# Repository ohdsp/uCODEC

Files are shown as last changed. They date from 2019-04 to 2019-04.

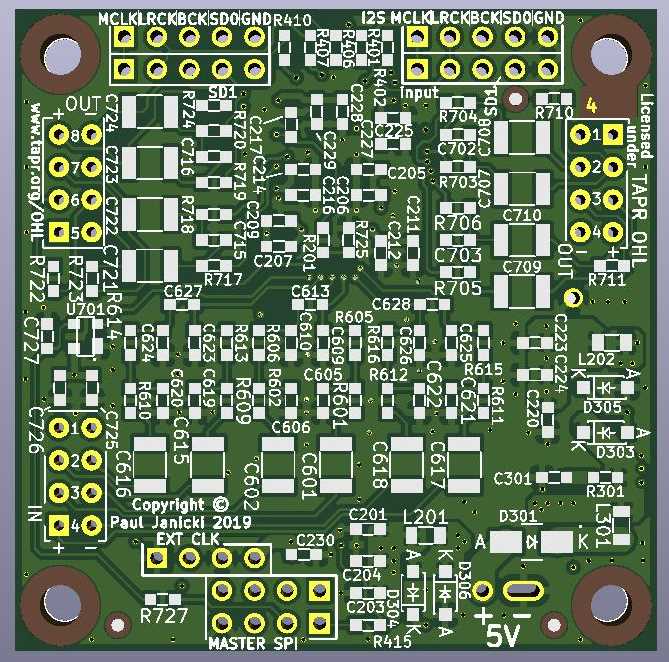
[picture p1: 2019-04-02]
JPEGs/uCODEC-1.0-Bottom-Small.jpg

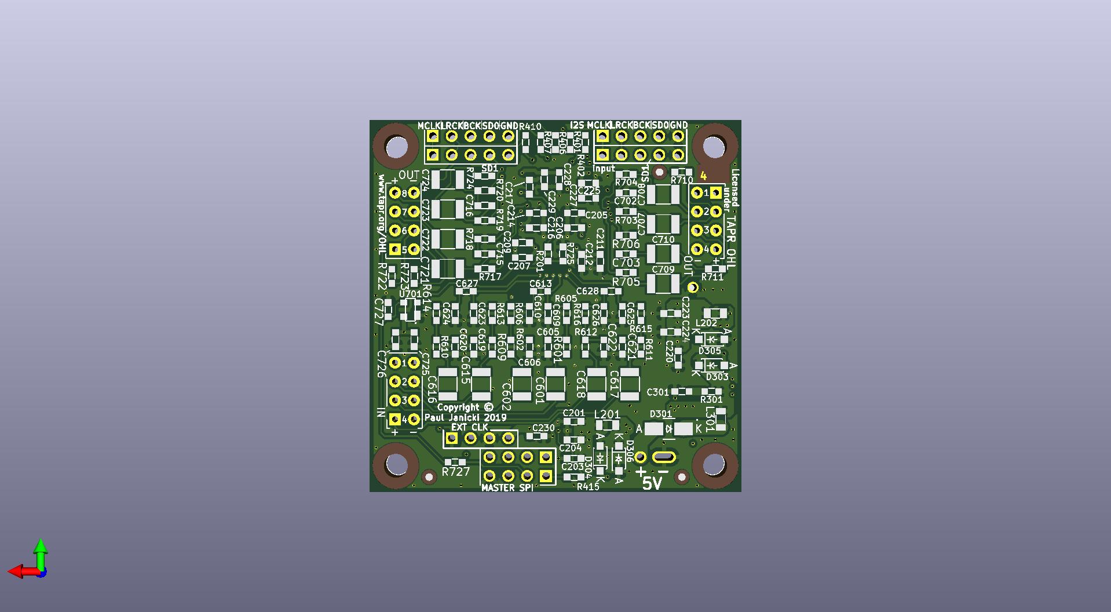
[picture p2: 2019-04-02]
JPEGs/uCODEC-1.0-Bottom.jpg

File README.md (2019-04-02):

# [Open Hardware DSP Platform](www.ohdsp.org)
## uCODEC 1.0 
### A 5cm x 5cm CODEC board using Analog Device AD1939
### 8 Differential Outputs
### 4 Differential Inputs
---
# README
### Disclaimer
Copyright Paul Janicki 2019

Licensed under the TAPR Open Hardware License (www.tapr.org/OHL)

This documentation is distributed WITHOUT ANY EXPRESS OR IMPLIED WARRANTY, INCLUDING OF MERCHANTABILITY, SATISFACTORY QUALITY AND FITNESS FOR A PARTICULAR PURPOSE.

### What is this repository for?

**Quick summary**

This is a simple 4 input, 8 output, ADC/DAC board using the Analog Devices AD1939 CODEC

This board forms part the of the open hardware DSP platform which is designed to be a highly customisable and flexible DSP platform. 

This repository contains the KiCad design files, manufacturing Gerber/drill files, and PDF/drawing files for this board.

### What is the project folder structure?
Most folder names are self explanatory. Starting from the top level:
*uCODEC*
+ *Bill of Materials*  - This contains the bill of materials in CVS, LibreOffice Calc and XML formats
+ *Drawings* - This contains PDF and SVG Schematic and PCB files
+ *Gerbers* - This contains the PCB Gerbers and drill drawings for manufacture, there is also a zip file ready to send to most manufacturers
+ *KiCad* - This contains the original KiCad schematic and PCB design files

### How do I get set up?

**Summary of set up**

1. Set your self up a directory on a local disk, something simple will make life easier (eg C:\Electronics on Windows as used here), but anywhere will do just fine.
2. Download the Kicad-Libs from [https://github.com/ohdsp/KiCad-Libs](https://github.com/ohdsp/KiCad-Libs) and place in C:\Electronics\Kicad-Libs (or your chosen folder) 
3. Create a OHDSP subdirectory in C:\Electronics (so C:\Electronics\OHDSP)
3. Download this project to C:\Electronics\OHDSP\uCODEC
4. Fire up Kicad
5. Open the main project file C:\Electronics\OHDSP\uCODEC\KiCad\uCODEC.pro
7. Do as you wish with the project, just keep it under the TAPR Open Hardware License.
Note: For library issues see below.

Make sure your git setup doesn't exclude files used in the project (like .LIB files) or things may go wrong down the line.

**KiCad Library Configuration**

Note that libraries are setup using relative paths, if you follow the above instructions things should work just fine. Below is the default library setup.

To setup eeschema component libraries:
From KiCad main window go to menu Tools -> Edit Schematic Symbols. In the new Window go to menu Preferences -> Manage Symbol Libraries.

On the new "Symbol Libraries" window select the "Project Specific Libraries" tab. The "Append Library" and "Remove Library" buttons can be used to add/remove enteries.
The standard setup is:

| | Active | Nickname | Library Path | Plugin Type | Options | Description |
|---|---|---|---|---|---|---|
| 1 | Ticked | power | ${KICAD_SYMBOL_DIR}/power.lib | Legacy | (blank) | (blank) |
| 2 | Ticked | MyKiCadLibs-Lib | ${KIPRJMOD}/../../../KiCad-Libs/MyKiCadLibs-Lib.lib | Legacy | (blank) | (blank) |

${KICAD_SYMBOL_DIR}  is set under the Enviromnet Variable Configuration. Close Symbol Libraries dialogue and go "Preferences" -> "Configure Paths..."

${KICAD_SYMBOL_DIR} is set to C:\Program Files\KiCad\share\kicad\library - this is the default for a KiCad install on the C drive

${KIPRJMOD} is automatically set to the location of the project (.pro file), in this example this would be C:\Electronics\OHDSP\uCODEC\KiCad

To setup Pcbnew libraries:
From KiCad main window go to menu Tools -> Edit PCB Footprints. In the new Window go to menu Preferences -> Manage Symbol Libraries.

On the new "Symbol Libraries" window select the "Project Specific Libraries" tab. The "Append Library" and "Remove Library" buttons can be used to add/remove enteries.
The standard setup is:

| | Active | Nickname | Library Path | Plugin Type | Options | Description |
|---|---|---|---|---|---|---|
| 1 | Ticked | MyKiCadLibs-Footprints | ${KIPRJMOD}/../../../KiCad-Libs/MyKiCadLibs-Footprints.pretty | KiCad | (blank) | (blank) |

${KIPRJMOD} is automatically set to the location of the project (.pro file), in this example this would be C:\Electronics\OHDSP\uCODEC\KiCad

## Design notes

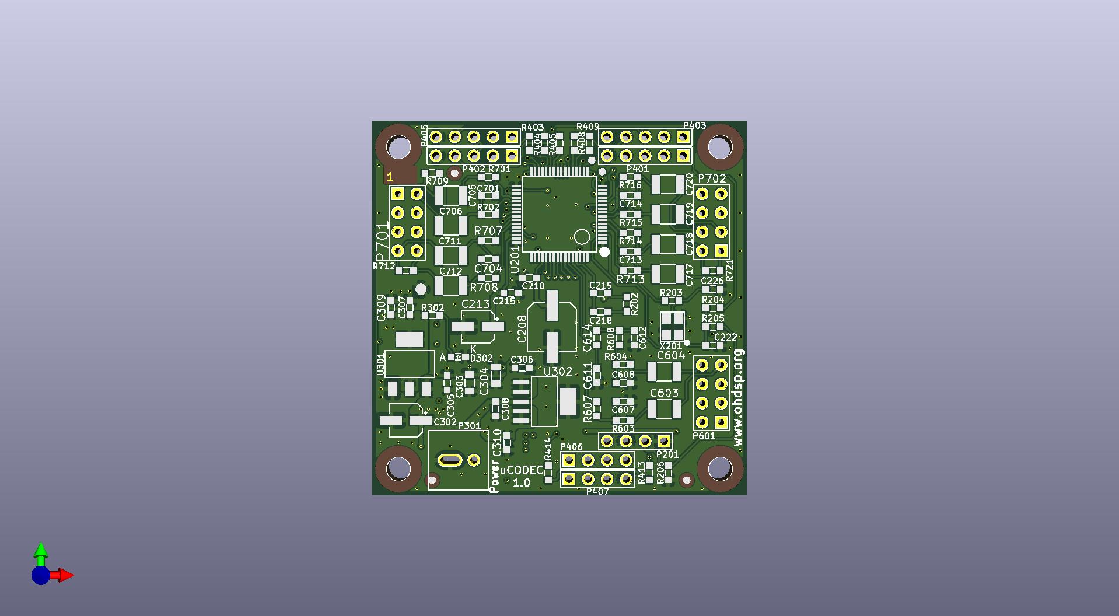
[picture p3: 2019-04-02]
JPEGs/uCODEC-1.0-Front.jpg

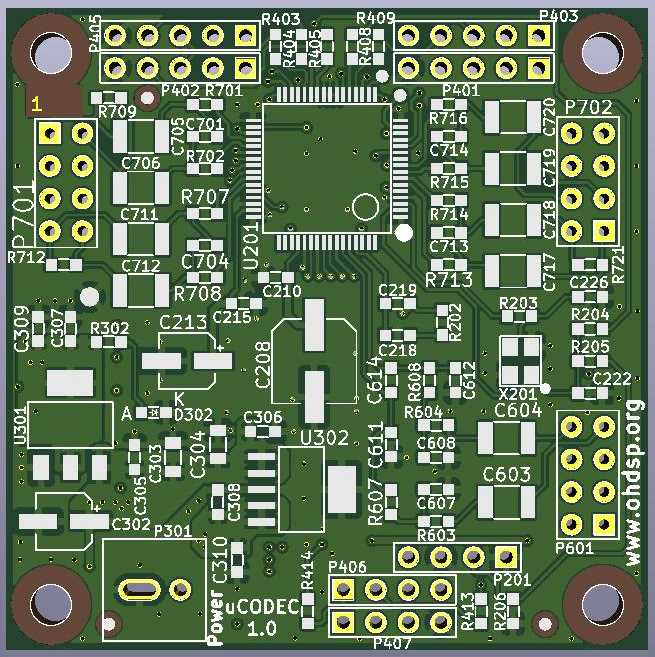
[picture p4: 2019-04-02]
JPEGs/uCODEC-1.0-Front-Small.jpg

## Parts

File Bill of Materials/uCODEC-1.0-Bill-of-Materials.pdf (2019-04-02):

ADC-PCM4202-SE-Bill-of-Materials-1.1

Page 1

### UCODEC-1.0 Bill of Materials 02 April 2019

Reference | Quantity | Footprint | Value | Description | Size | Tolerance | Type | Voltag | Power | Current
C201 C220 C301 | 3 SMD-0603 | | 100p | 'Ceramic capacitor | '0603 | '5% | 'NP0 | '50V | ' | '
C204 C205 C207 C210 C211 C214 C215 C224 C225 C228 C230 C305 C306 C307 C308 C726 | 16 SMD-0603 | | 100n | 'Ceramic capacitor | '0603 | '10% | 'X7R | '50V | ' | '
C206 C209 C212 C216 C217 C227 C229 C727 | 8 SMD-0603 | | 10n | 'Ceramic capacitor | '0603 | '10% | 'X7R | '50V | ' | '
C208 | 1 CAP-SMD-SIZE-D | | 47u | 'Low impedance aluminium electrolytic capacitor - Panasonic FP, FK or Similar | ' | ' | 'Case D SM'16V | | ' | '
C213 C302 | 2 CAP-SMD-SIZE-B | | 10u | 'Low impedance aluminium electrolytic capacitor - Panasonic FP, FK or Similar | ' | ' | 'Case B SM'16V | | ' | '
C218 | 1 SMD-0603 | | 39n | 'Ceramic capacitor | '0603 | '10% | 'X7R | '50V | ' | '
C219 | 1 SMD-0603 | | 2n2 | 'Ceramic capacitor | '0603 | '5% | 'C0G | '50V | ' | '
C222 C226 | 2 SMD-0603 | | N/F | 'Ceramic capacitor | '0603 | '5% | 'C0G | '25V | ' | '
C203 C223 C309 C310 | 4 SMD-0603 | | 22u | 'Ceramic capacitor | '0603 | '20% | 'X5R | '10V | ' | '
C303 C304 C605 C606 C607 C608 C613 C614 C619 C620 C621 C622 C627 | 2 SMD-0805 | | 22u | 'Ceramic capacitor | '0805 | '20% | 'X5R | '25V | ' | '
C628 | 12 SMD-0603 | | 100p | 'Ceramic capacitor | '0603 | '5% | 'C0G | '50V | ' | '
C609 C610 C611 C612 C623 C624 C625 C626 C701 C702 C703 C704 C713 C714 C715 C716 C601 C602 C603 C604 C615 C616 C617 C618 C705 C706 C707 | 16 SMD-0603 | | 1n | 'Ceramic capacitor | '0603 | '5% | 'C0G | '50V | ' | '
C708 C709 C710 C711 C712 C717 C718 C719 C720 C721 C722 C723 C724 | 24 SMD-1210 | | 1u | 'Acrylic capacitor | '1210 | '20% | 'Acrylic | '16V | ' | '
C725 | 1 SMD-0603 | | 10u | 'Ceramic capacitor | '0603 | '20% | 'X5R | '10V | ' | '
D301 | 1 DIODE-SMA | | B240A | 'B240A 2A 40V Schottky Rectifier - SMA (DO-214AC) | ' | ' | ' | ' | ' | '
D302 | 1 SMD-0603-LED | | LED 0603 | 'LED - SMD - Vf 1.8V to 2.2V | '0603 | ' | ' | ' | ' | '
D303 D304 D305 D306 | 4 DIODE-SOD-123 | | 1N5819HW | '1A 40V Schottky Rectifier - SOD-123 | ' | ' | ' | ' | ' | '
L201 L202 L301 | 3 SMD-0805 | | 600R@100MHz | 'Ferrite bead, current rating 1A or higher, 600R@100MHz | '0805 | ' | ' | ' | ' | '=>1A
P201 P406 P407 | 3 CONN_SIL_4_1MM | | CONN_4x1 | '2.54mm 4 way pin header or socket | ' | ' | ' | ' | ' | '
P301 | 1 CONN-2WAY-2.54mm-3.81mm-SPACING | | CONN_2x1 | '2 way screw terminal, any 2.54mm to 3.81mm pitch part | ' | ' | ' | ' | ' | '
P401 P402 P403 P405 | 4 CONN_SIL_5_1MM | | CONN_5x1 | '2.54mm 5 way pin header or socket | ' | ' | ' | ' | ' | '
P601 P701 P702 | 3 CONN_DIL_2X04 | | CONN_02X04 | '2.54mm 2x4 way pin header or socket or direct solder | ' | ' | ' | ' | ' | '
R202 | 1 SMD-0603 | | 3K32 | 'Thick or thin film resistor | '0603 | '1% | ' | ' | '63mW | '
R203 R205 R206 R406 R414 | 5 SMD-0603 | | N/F | 'Thick or thin film resistor | '0603 | '1% | ' | ' | '63mW | '
R201 R204 R404 R405 R413 R415 | 6 SMD-0603 | | 22 | 'Thick or thin film resistor | '0603 | '1% | ' | ' | '63mW | '
R301 | 1 SMD-0603 | | 47 | 'Thick or thin film resistor | '0603 | '1% | ' | ' | '63mW | '
R302 | 1 SMD-0603 | | 470 | 'Thick or thin film resistor | '0603 | '1% | ' | ' | '63mW | '
R401 R402 R403 R407 R408 R409 R410 | 7 SMD-0603 | | 0 | 'Thick or thin film resistor | '0603 | '1% | ' | ' | '63mW | '
R605 R606 R607 R608 R613 R614 R615 R616 R601 R602 R603 R604 R609 R610 R611 R612 R701 R702 R703 | 8 SMD-0603 | | 220 | 'Thick or thin film resistor | '0603 | '1% | ' | ' | '63mW | '
R704 R705 R706 R707 R708 R713 R714 R715 R716 R717 R718 R719 R720 | 24 SMD-0603 | | 1K | 'Thick or thin film resistor | '0603 | '1% | ' | ' | '63mW | '
R709 R710 R711 R712 R721 R722 R723 R724 | 8 SMD-0603 | | 220K | 'Thick or thin film resistor | '0603 | '1% | ' | ' | '63mW | '
R725 | 1 SMD-0603 | | 100K | 'Thick or thin film resistor | '0603 | '1% | ' | ' | '63mW | '
R727 | 1 SMD-0603 | | 100 | 'Thick or thin film resistor | '0603 | '1% | ' | ' | '63mW | '
U201 | 1 IC-LQFP64 | | AD1939 | 'Analog Devices AD1939WBSTZ - 4 ADC/8 DAC with PLL | ' | ' | ' | ' | ' | '
U301 | 1 IC-SOT-223 | | TLV1117LV33DCY | 'TLV1117LV 1-A, Positive Fixed-Voltage, Low-Dropout Regulator - Fixed 3V3 | ' | ' | ' | ' | ' | '
U302 | 1 IC-SOT223-6 | | TPS7A4533DCQ | 'TI TPS7A45xx Regulator | ' | ' | ' | ' | ' | '
U701 | 1 IC-SOT143 | | CAT811TTBI | 'CAT811/ADM811 - 4-Pin Microprocessor Power Supply Supervisor with Manual Reset - Active Low | ' | ' | ' | ' | ' | '
X201 | 1 XTAL_3.2x2.5_4PIN | | N/F | 'Not Fitted - 3.2x2.5mm crystal | ' | ' | ' | ' | ' | '

Licensed under the TAPR Open Hardware License (www.tapr.org/OHL)

Open Hardware DSP Platform www.ohdsp.org

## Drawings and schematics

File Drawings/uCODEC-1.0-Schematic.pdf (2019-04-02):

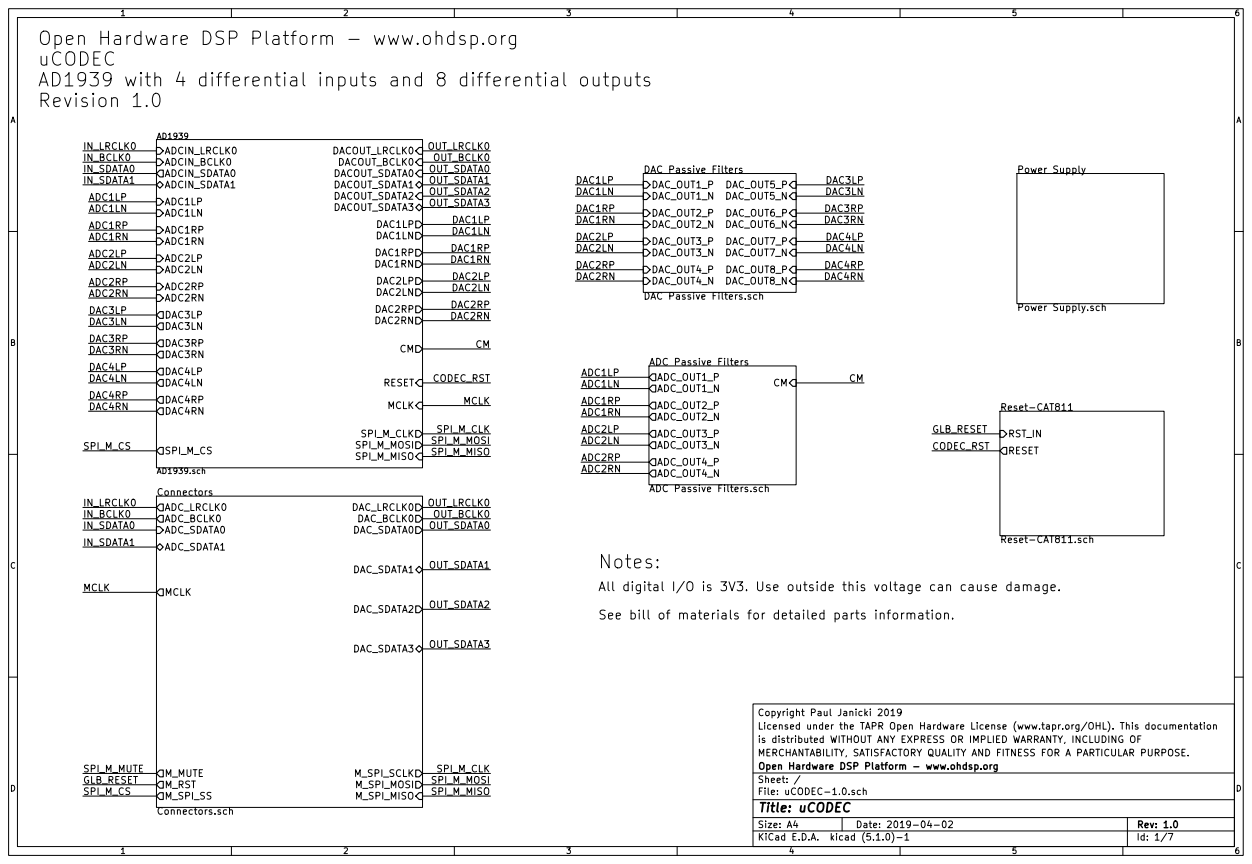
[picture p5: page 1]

Open Hardware DSP Platform - www.ohdsp.org
uCODEC
AD1939 with 4 differential inputs and 8 differential outputs
Revision 1.0

IN_BCLK0
IN_SDATA0 | OUT_SDATA0
IN_SDATA1 | OUT_SDATA1

SPI_M_MOSI
SPI_M_MISO

IN_BCLK0 | OUT_BCLK0

All digital I/O is 3V3. Use outside this voltage can cause damage.
See bill of materials for detailed parts information.

Copyright Paul Janicki 2019
Licensed under the TAPR Open Hardware License (www.tapr.org/OHL). This documentation
is distributed WITHOUT ANY EXPRESS OR IMPLIED WARRANTY, INCLUDING OF
MERCHANTABILITY, SATISFACTORY QUALITY AND FITNESS FOR A PARTICULAR PURPOSE.
File: uCODEC-1.0.sch Sheet: / Open Hardware DSP Platform - www.ohdsp.org

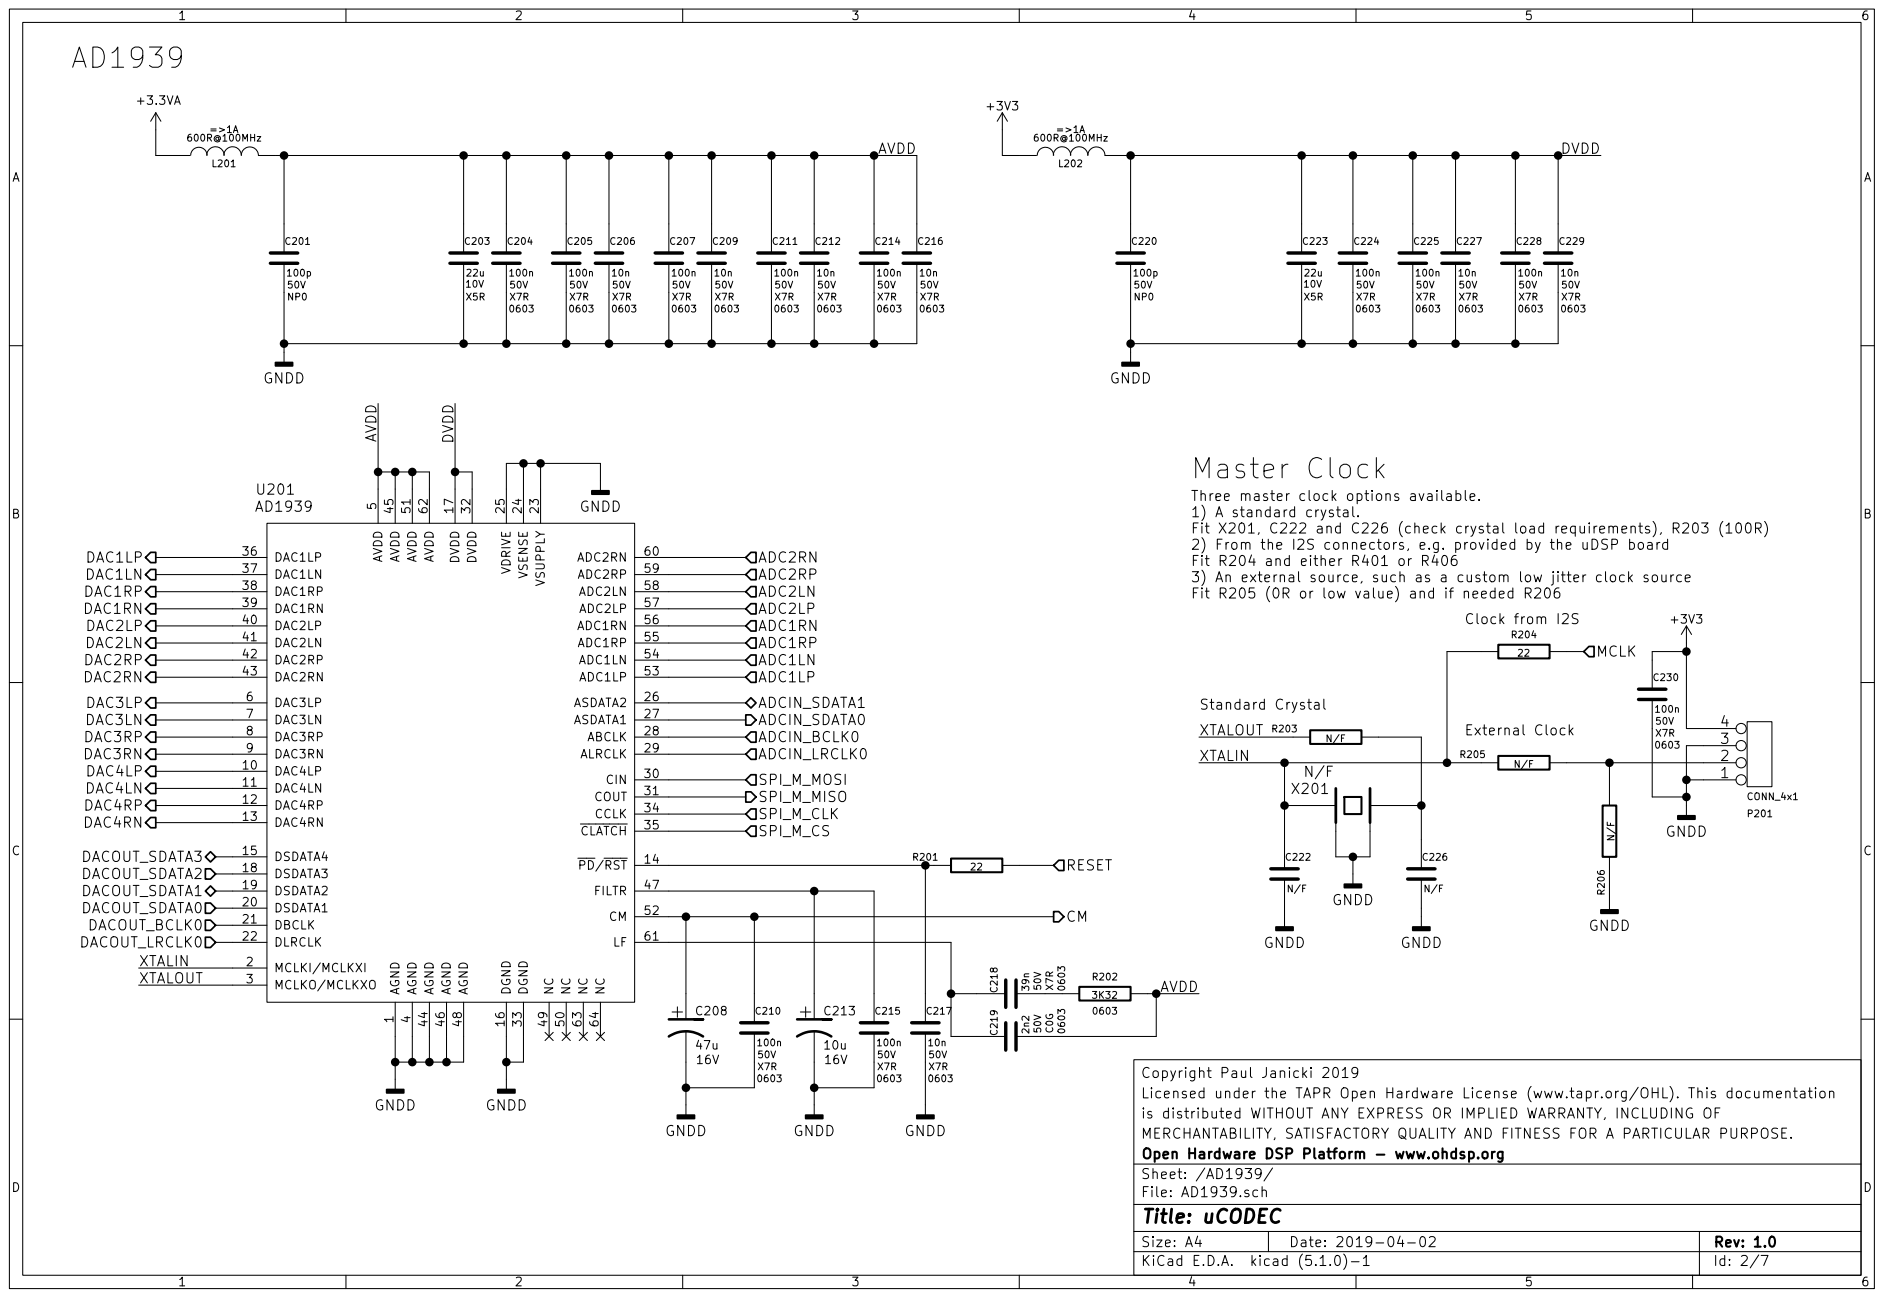
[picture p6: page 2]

4 DAC2LP 40 DAC2LN 41 DAC2RP 42 DAC2RN 43 AGND 44 AVDD 45 AGND 46 FILTR 47 AGND 48 NC 49 AVDD

Three master clock options available.
1) A standard crystal.
Fit X201, C222 and C226 (check crystal load requirements), R203 (100R)
2) From the I2S connectors, e.g. provided by the uDSP board Fit R204 and either R401 or R406

3) An external source, such as a custom low jitter clock source
Fit R205 (0R or low value) and if needed R206

Copyright Paul Janicki 2019
Licensed under the TAPR Open Hardware License (www.tapr.org/OHL). This documentation
is distributed WITHOUT ANY EXPRESS OR IMPLIED WARRANTY, INCLUDING OF
MERCHANTABILITY, SATISFACTORY QUALITY AND FITNESS FOR A PARTICULAR PURPOSE.
File: AD1939.sch Sheet: /AD1939/ Open Hardware DSP Platform - www.ohdsp.org

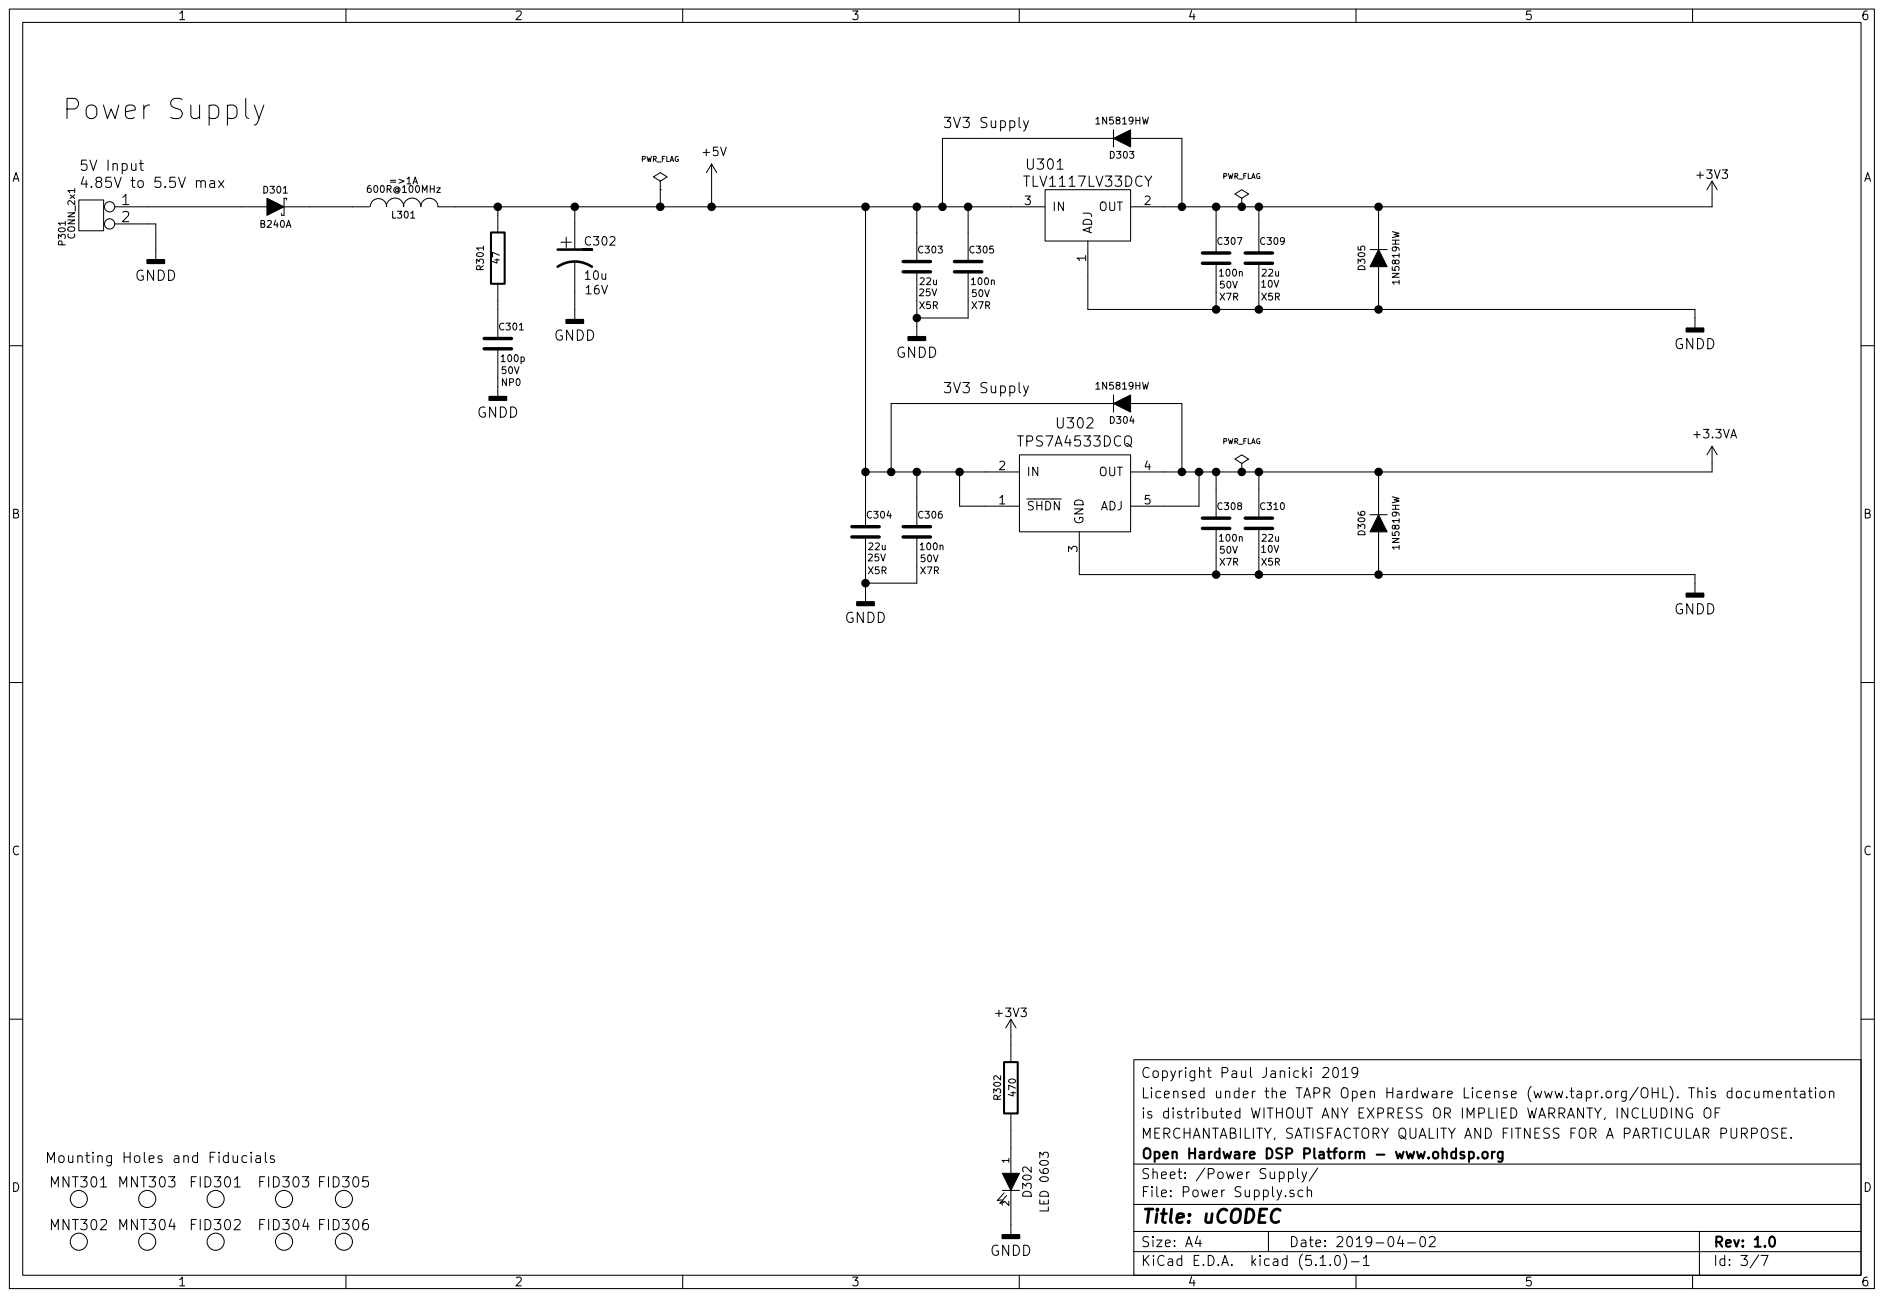
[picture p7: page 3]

Copyright Paul Janicki 2019
Licensed under the TAPR Open Hardware License (www.tapr.org/OHL). This documentation
is distributed WITHOUT ANY EXPRESS OR IMPLIED WARRANTY, INCLUDING OF
MERCHANTABILITY, SATISFACTORY QUALITY AND FITNESS FOR A PARTICULAR PURPOSE.
Open Hardware DSP Platform - www.ohdsp.org
Sheet: /Power Supply/
File: Power Supply.sch
Id: 3/7 Title: uCODEC

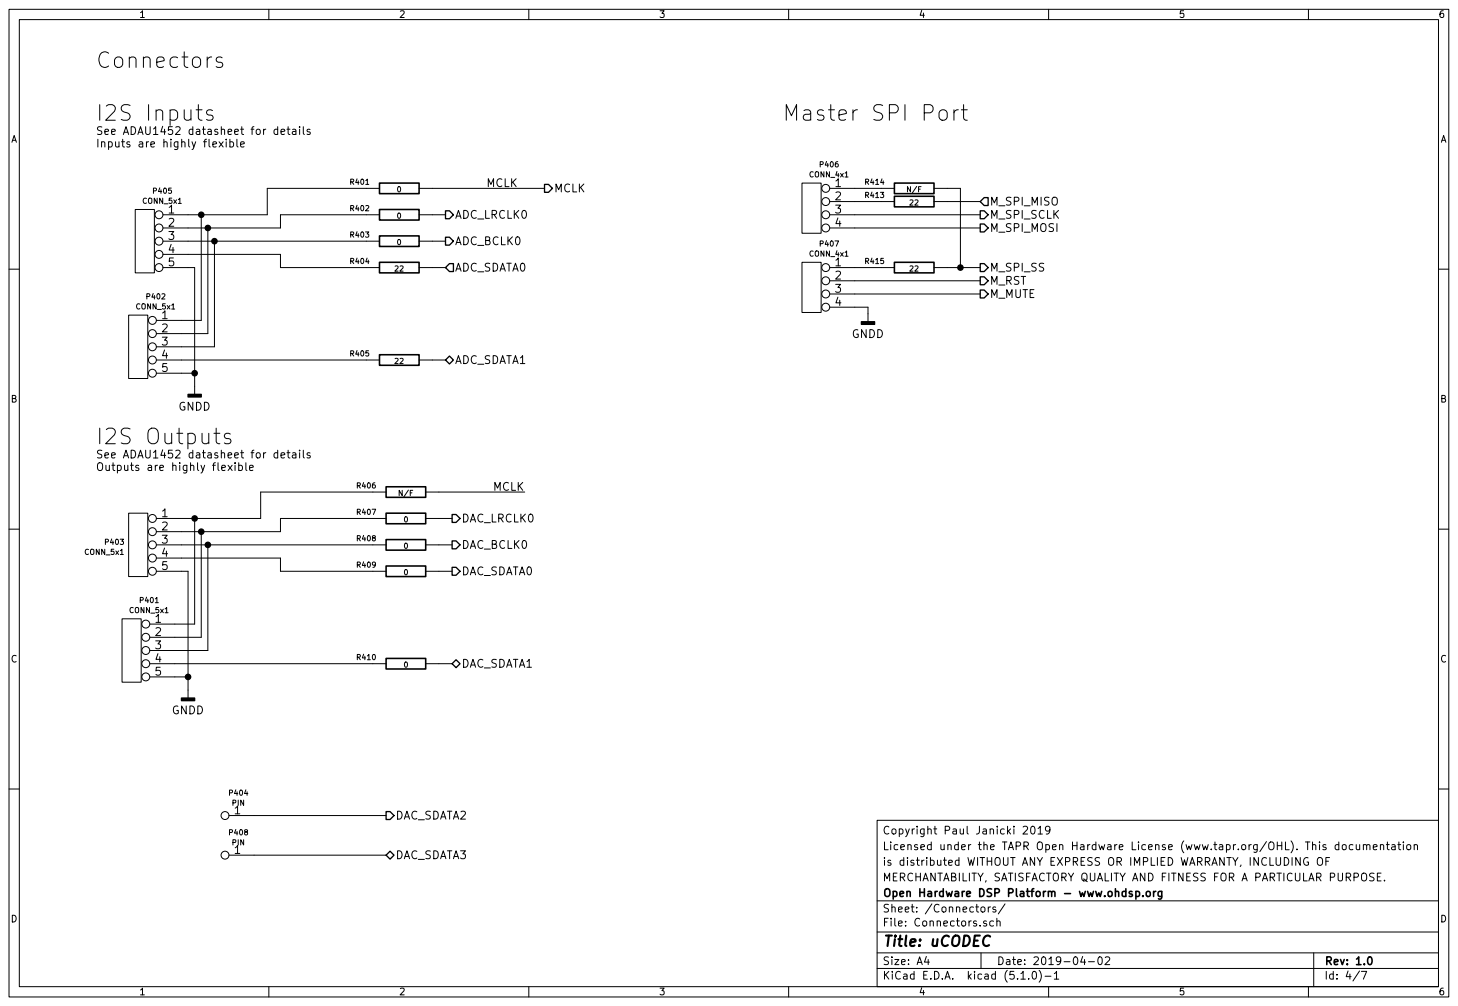
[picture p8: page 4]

I2S Inputs
See ADAU1452 datasheet for details
Inputs are highly flexible

I2S Outputs
See ADAU1452 datasheet for details Outputs are highly flexible

Copyright Paul Janicki 2019
Licensed under the TAPR Open Hardware License (www.tapr.org/OHL). This documentation
is distributed WITHOUT ANY EXPRESS OR IMPLIED WARRANTY, INCLUDING OF
MERCHANTABILITY, SATISFACTORY QUALITY AND FITNESS FOR A PARTICULAR PURPOSE.
File: Connectors.sch Sheet: /Connectors/ Open Hardware DSP Platform - www.ohdsp.org

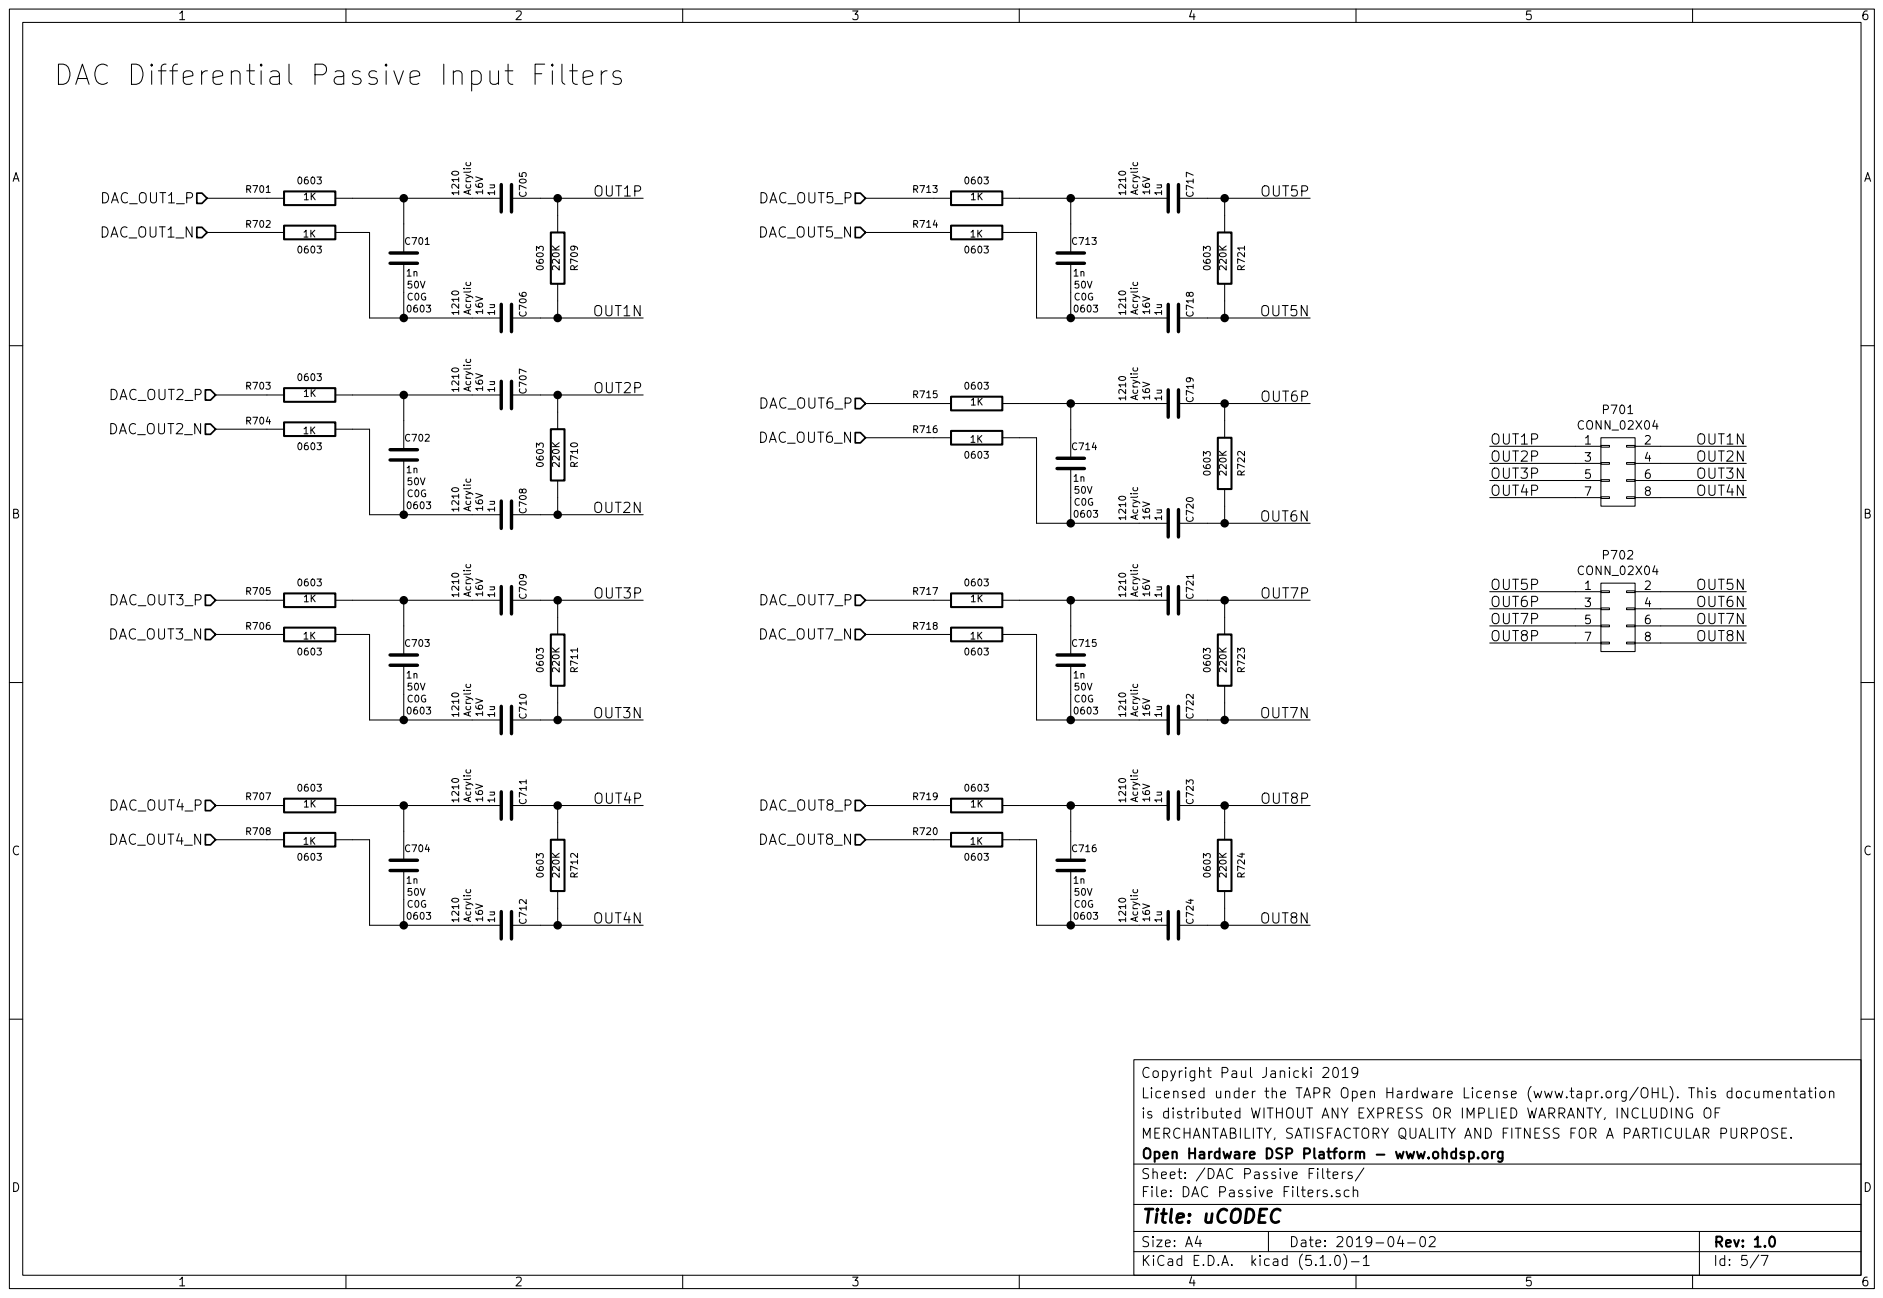
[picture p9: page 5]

DAC Differential Passive Input Filters

Licensed under the TAPR Open Hardware License (www.tapr.org/OHL). This documentation
is distributed WITHOUT ANY EXPRESS OR IMPLIED WARRANTY, INCLUDING OF
MERCHANTABILITY, SATISFACTORY QUALITY AND FITNESS FOR A PARTICULAR PURPOSE.
File: DAC Passive Filters.sch Sheet: /DAC Passive Filters/ Open Hardware DSP Platform - www.ohdsp.org

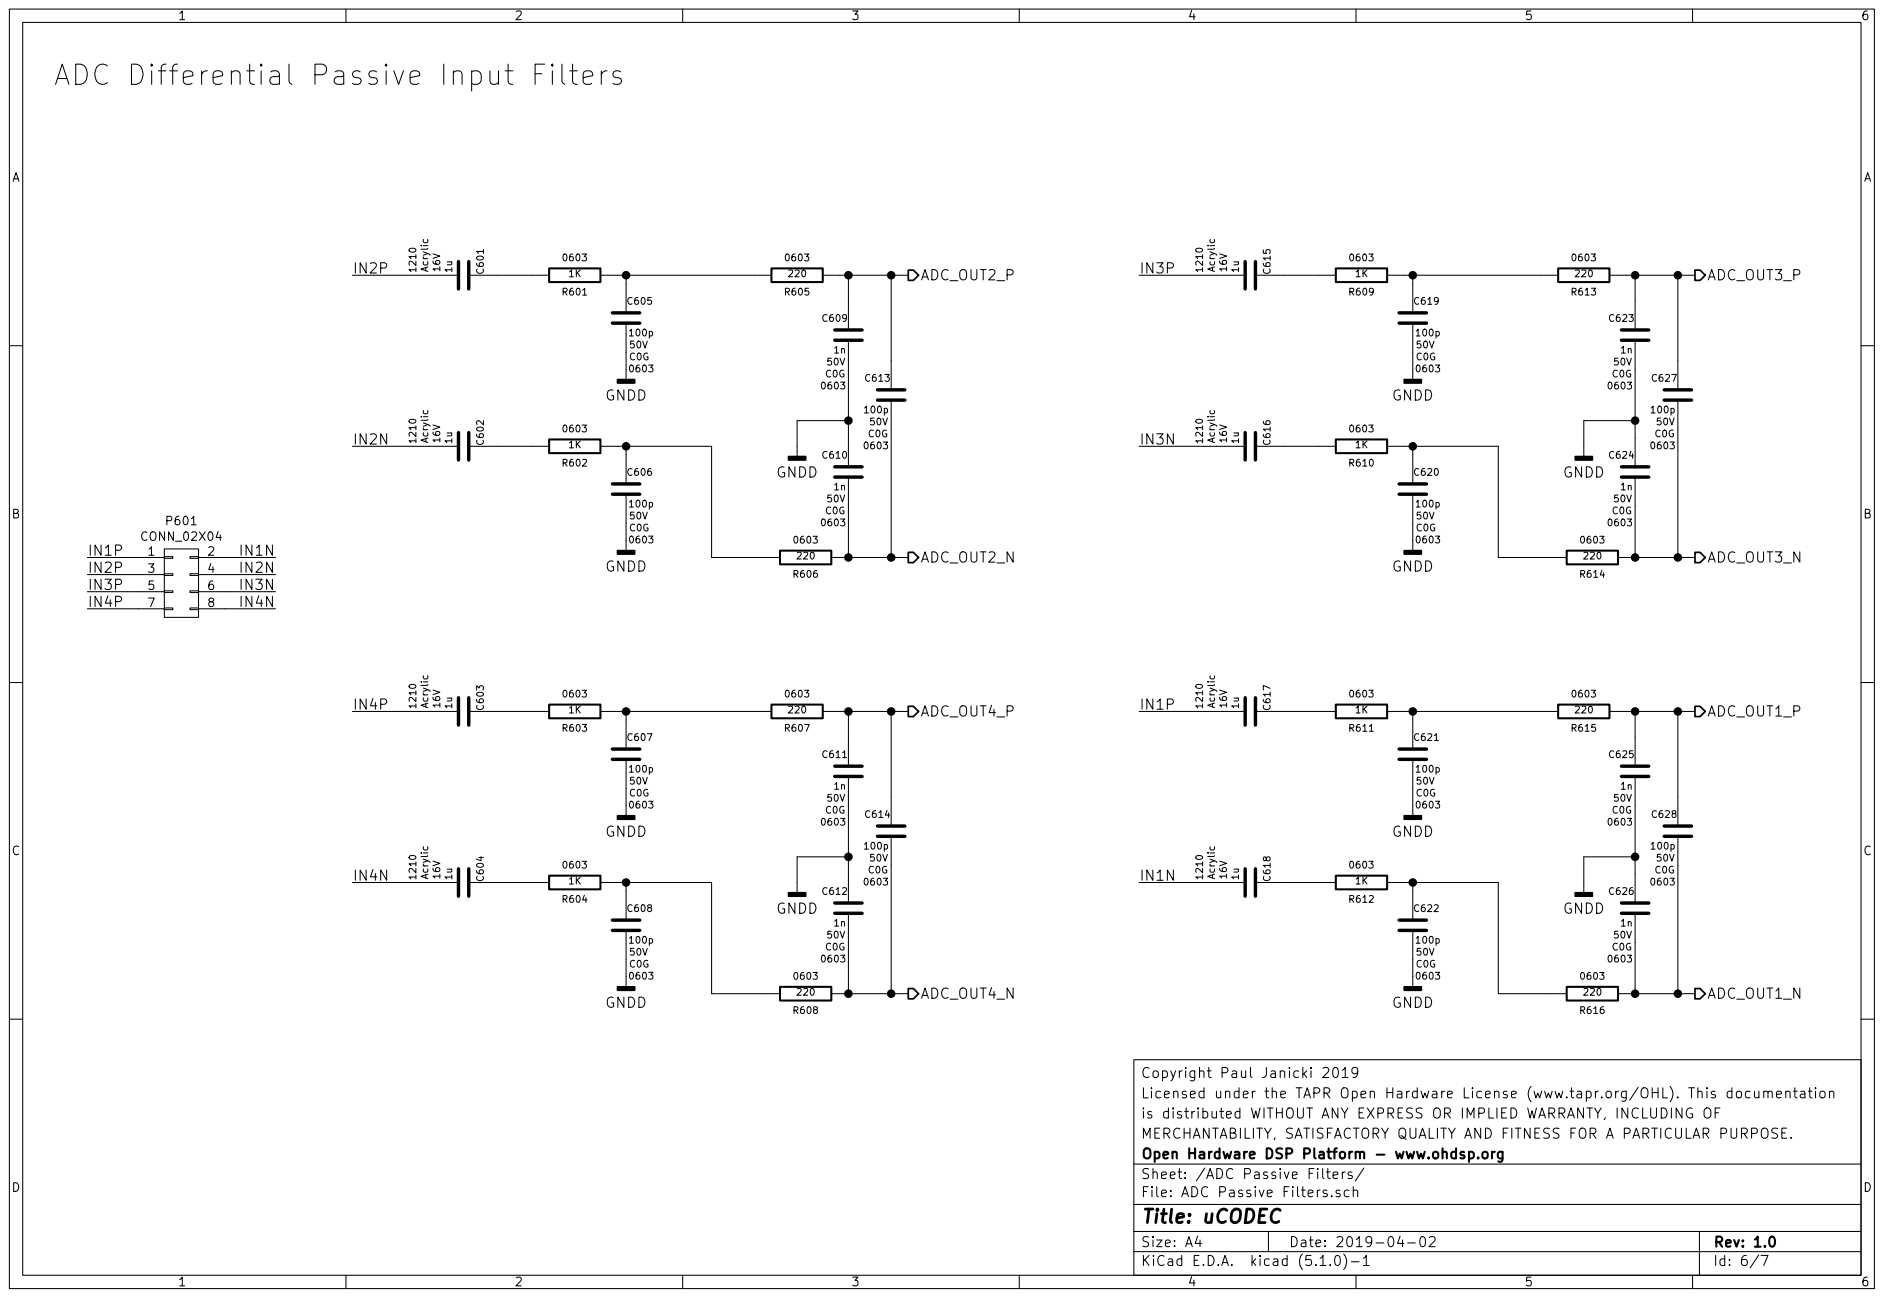
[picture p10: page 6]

ADC Differential Passive Input Filters

Copyright Paul Janicki 2019
Licensed under the TAPR Open Hardware License (www.tapr.org/OHL). This documentation
is distributed WITHOUT ANY EXPRESS OR IMPLIED WARRANTY, INCLUDING OF
MERCHANTABILITY, SATISFACTORY QUALITY AND FITNESS FOR A PARTICULAR PURPOSE.
File: ADC Passive Filters.sch Sheet: /ADC Passive Filters/ Open Hardware DSP Platform - www.ohdsp.org

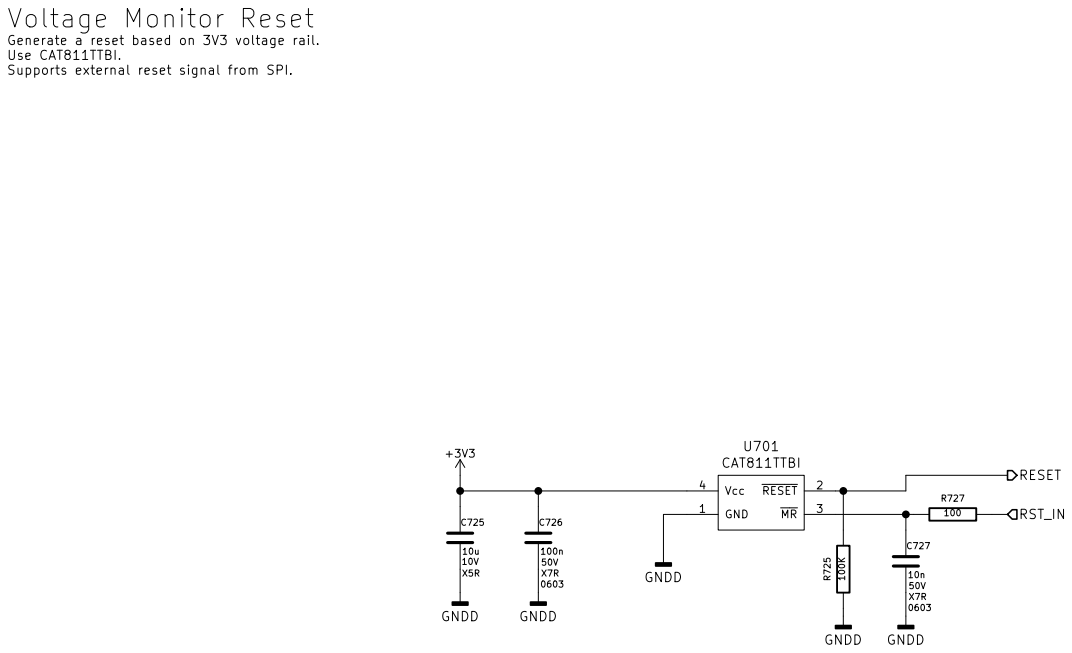
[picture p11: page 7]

Generate a reset based on 3V3 voltage rail. Use CAT811TTBI. Supports external reset signal from SPI.

Copyright Paul Janicki 2019
Licensed under the TAPR Open Hardware License (www.tapr.org/OHL). This documentation
is distributed WITHOUT ANY EXPRESS OR IMPLIED WARRANTY, INCLUDING OF
MERCHANTABILITY, SATISFACTORY QUALITY AND FITNESS FOR A PARTICULAR PURPOSE.
File: Reset-CAT811.sch Sheet: /Reset-CAT811/ Open Hardware DSP Platform - www.ohdsp.org

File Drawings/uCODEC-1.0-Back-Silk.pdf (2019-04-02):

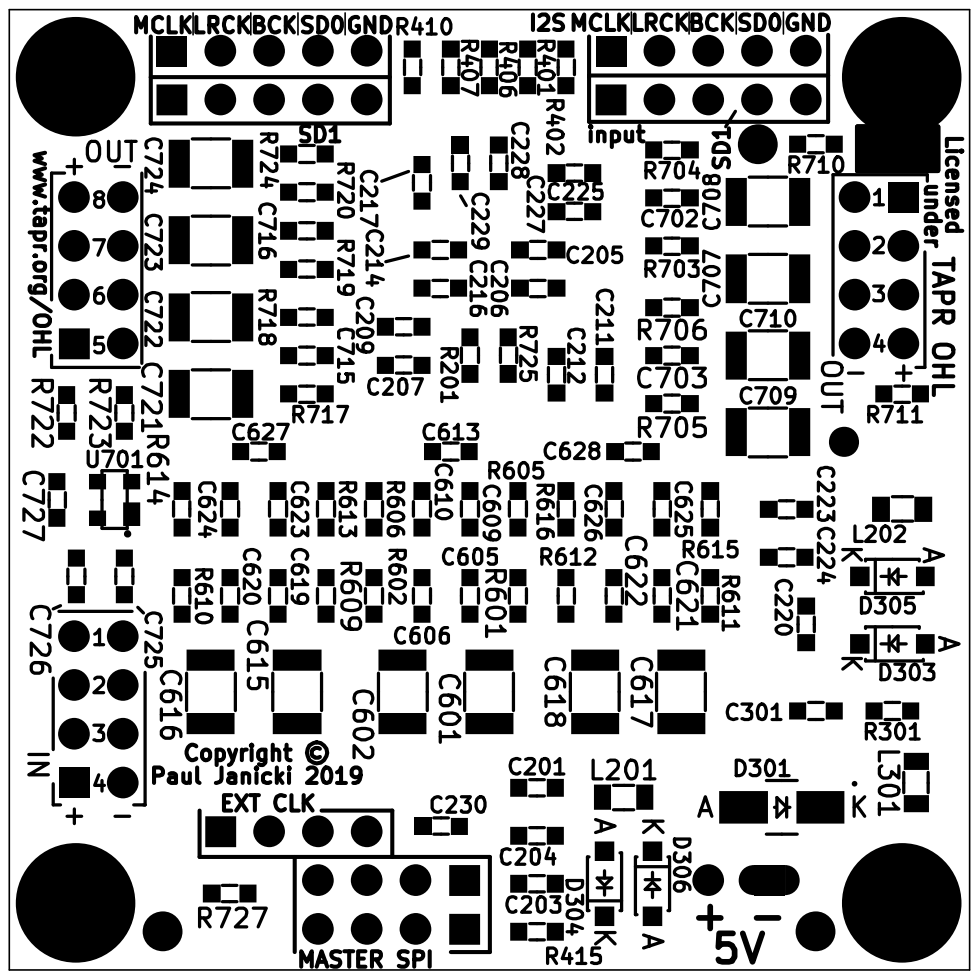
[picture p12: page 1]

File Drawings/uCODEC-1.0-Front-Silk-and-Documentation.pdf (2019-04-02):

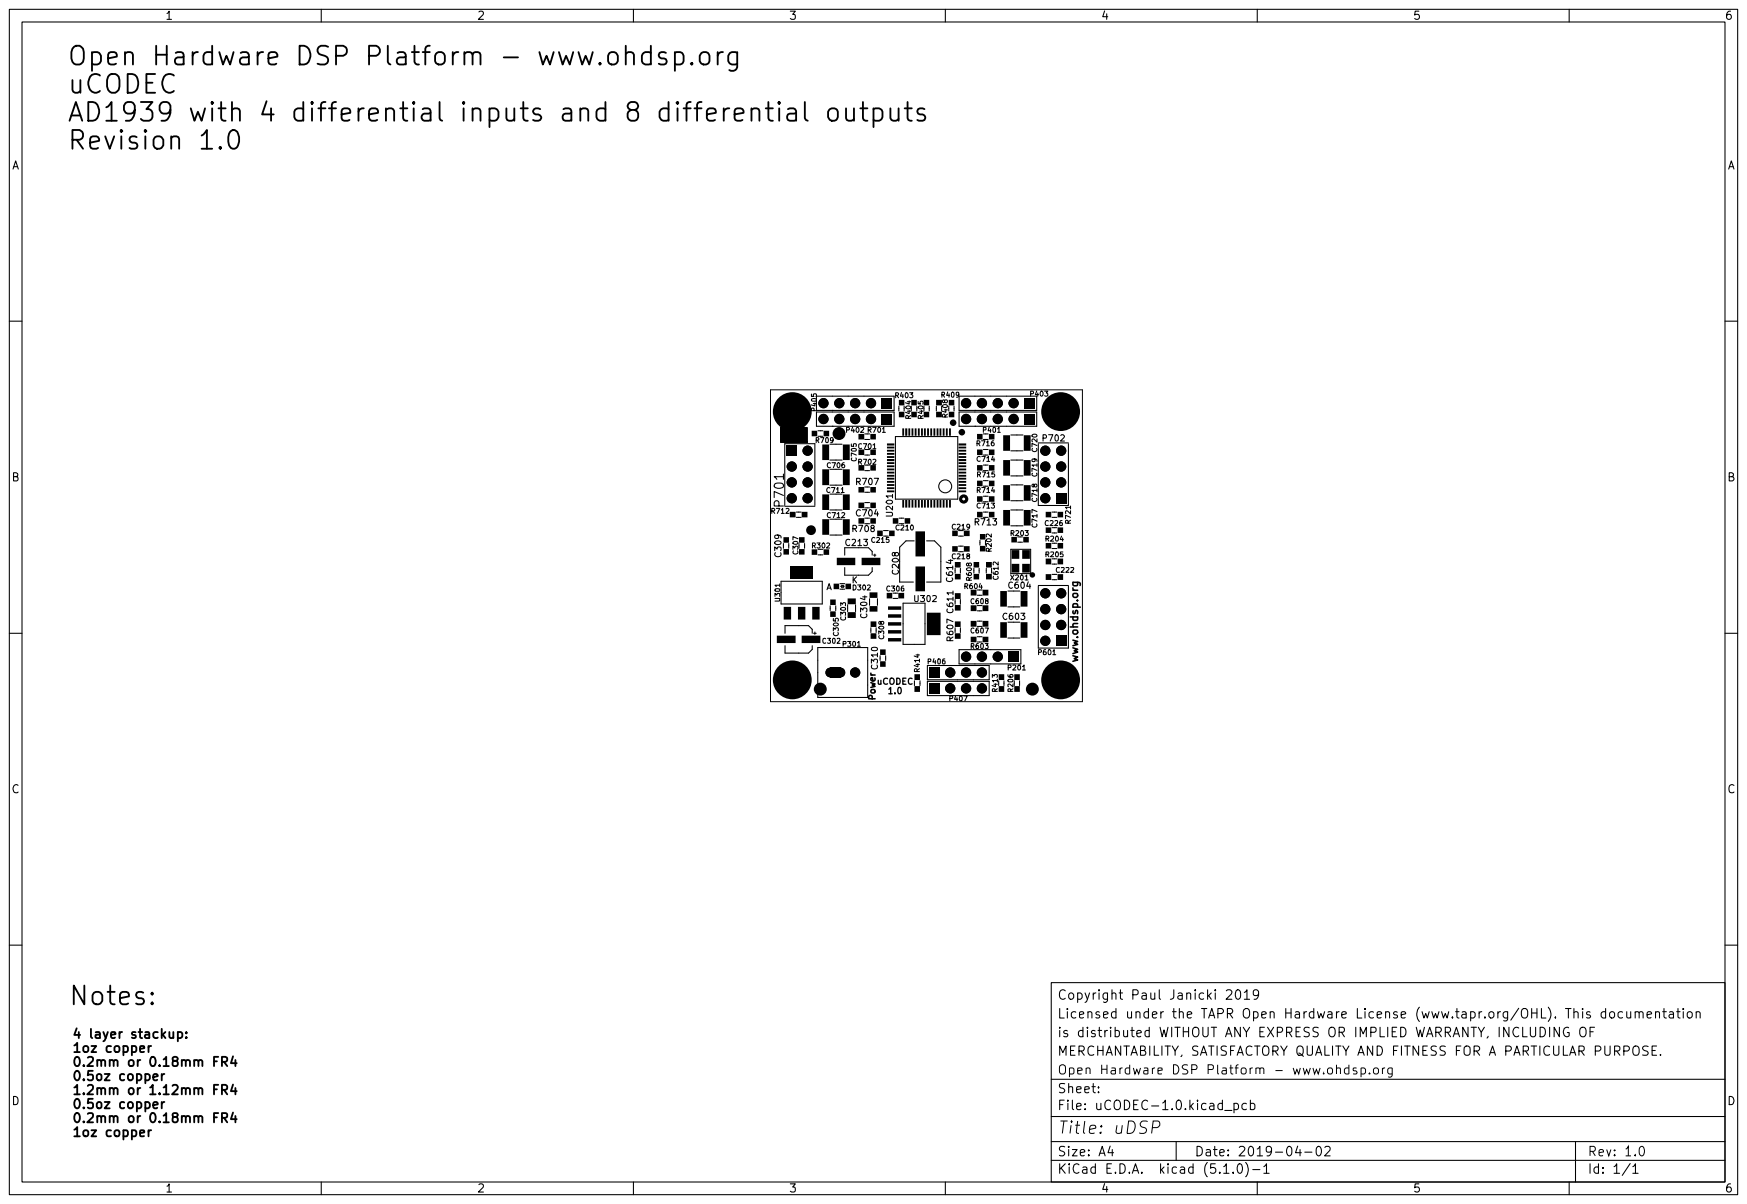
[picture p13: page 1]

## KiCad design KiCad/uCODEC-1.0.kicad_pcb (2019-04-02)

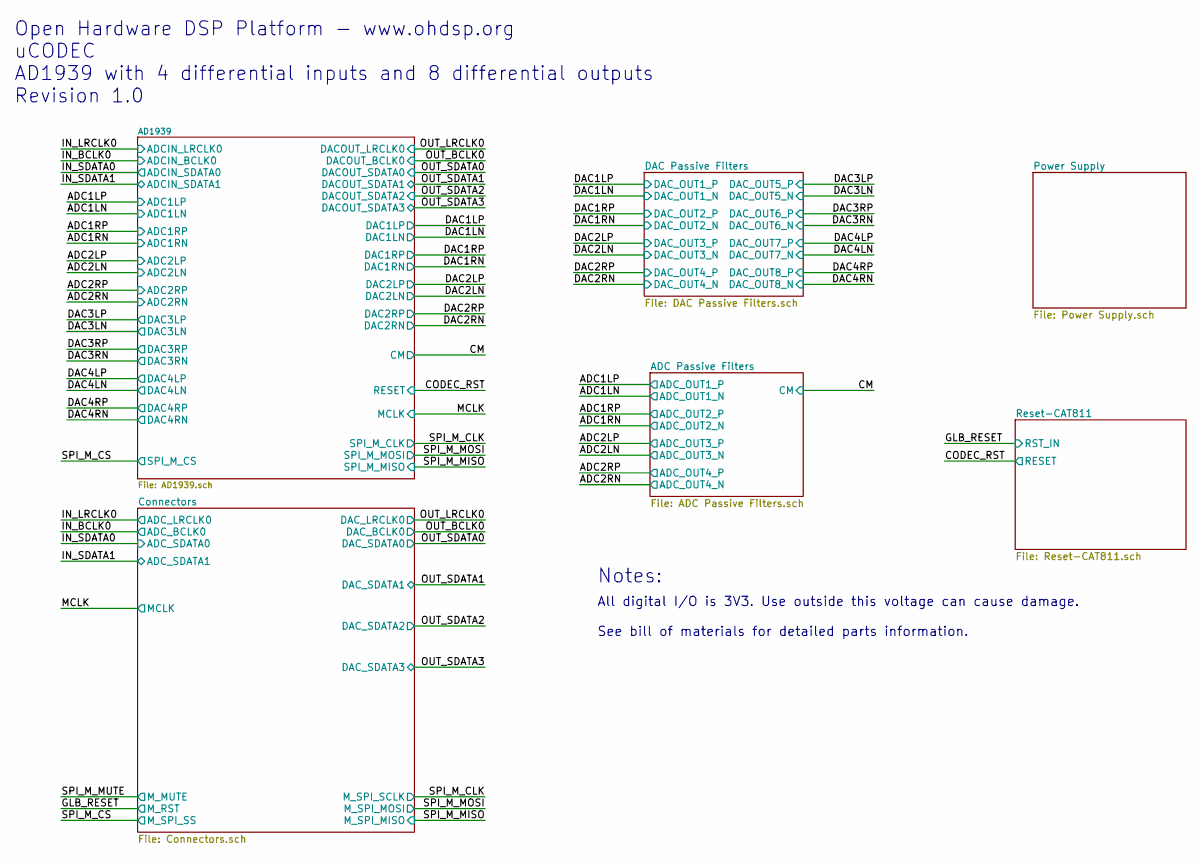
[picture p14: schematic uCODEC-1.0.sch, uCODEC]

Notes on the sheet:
All digital I/O is 3V3. Use outside this voltage can cause damage. See bill of materials for detailed parts information.
Notes:
Open Hardware DSP Platform - www.ohdsp.org uCODEC AD1939 with 4 differential inputs and 8 differential outputs Revision 1.0

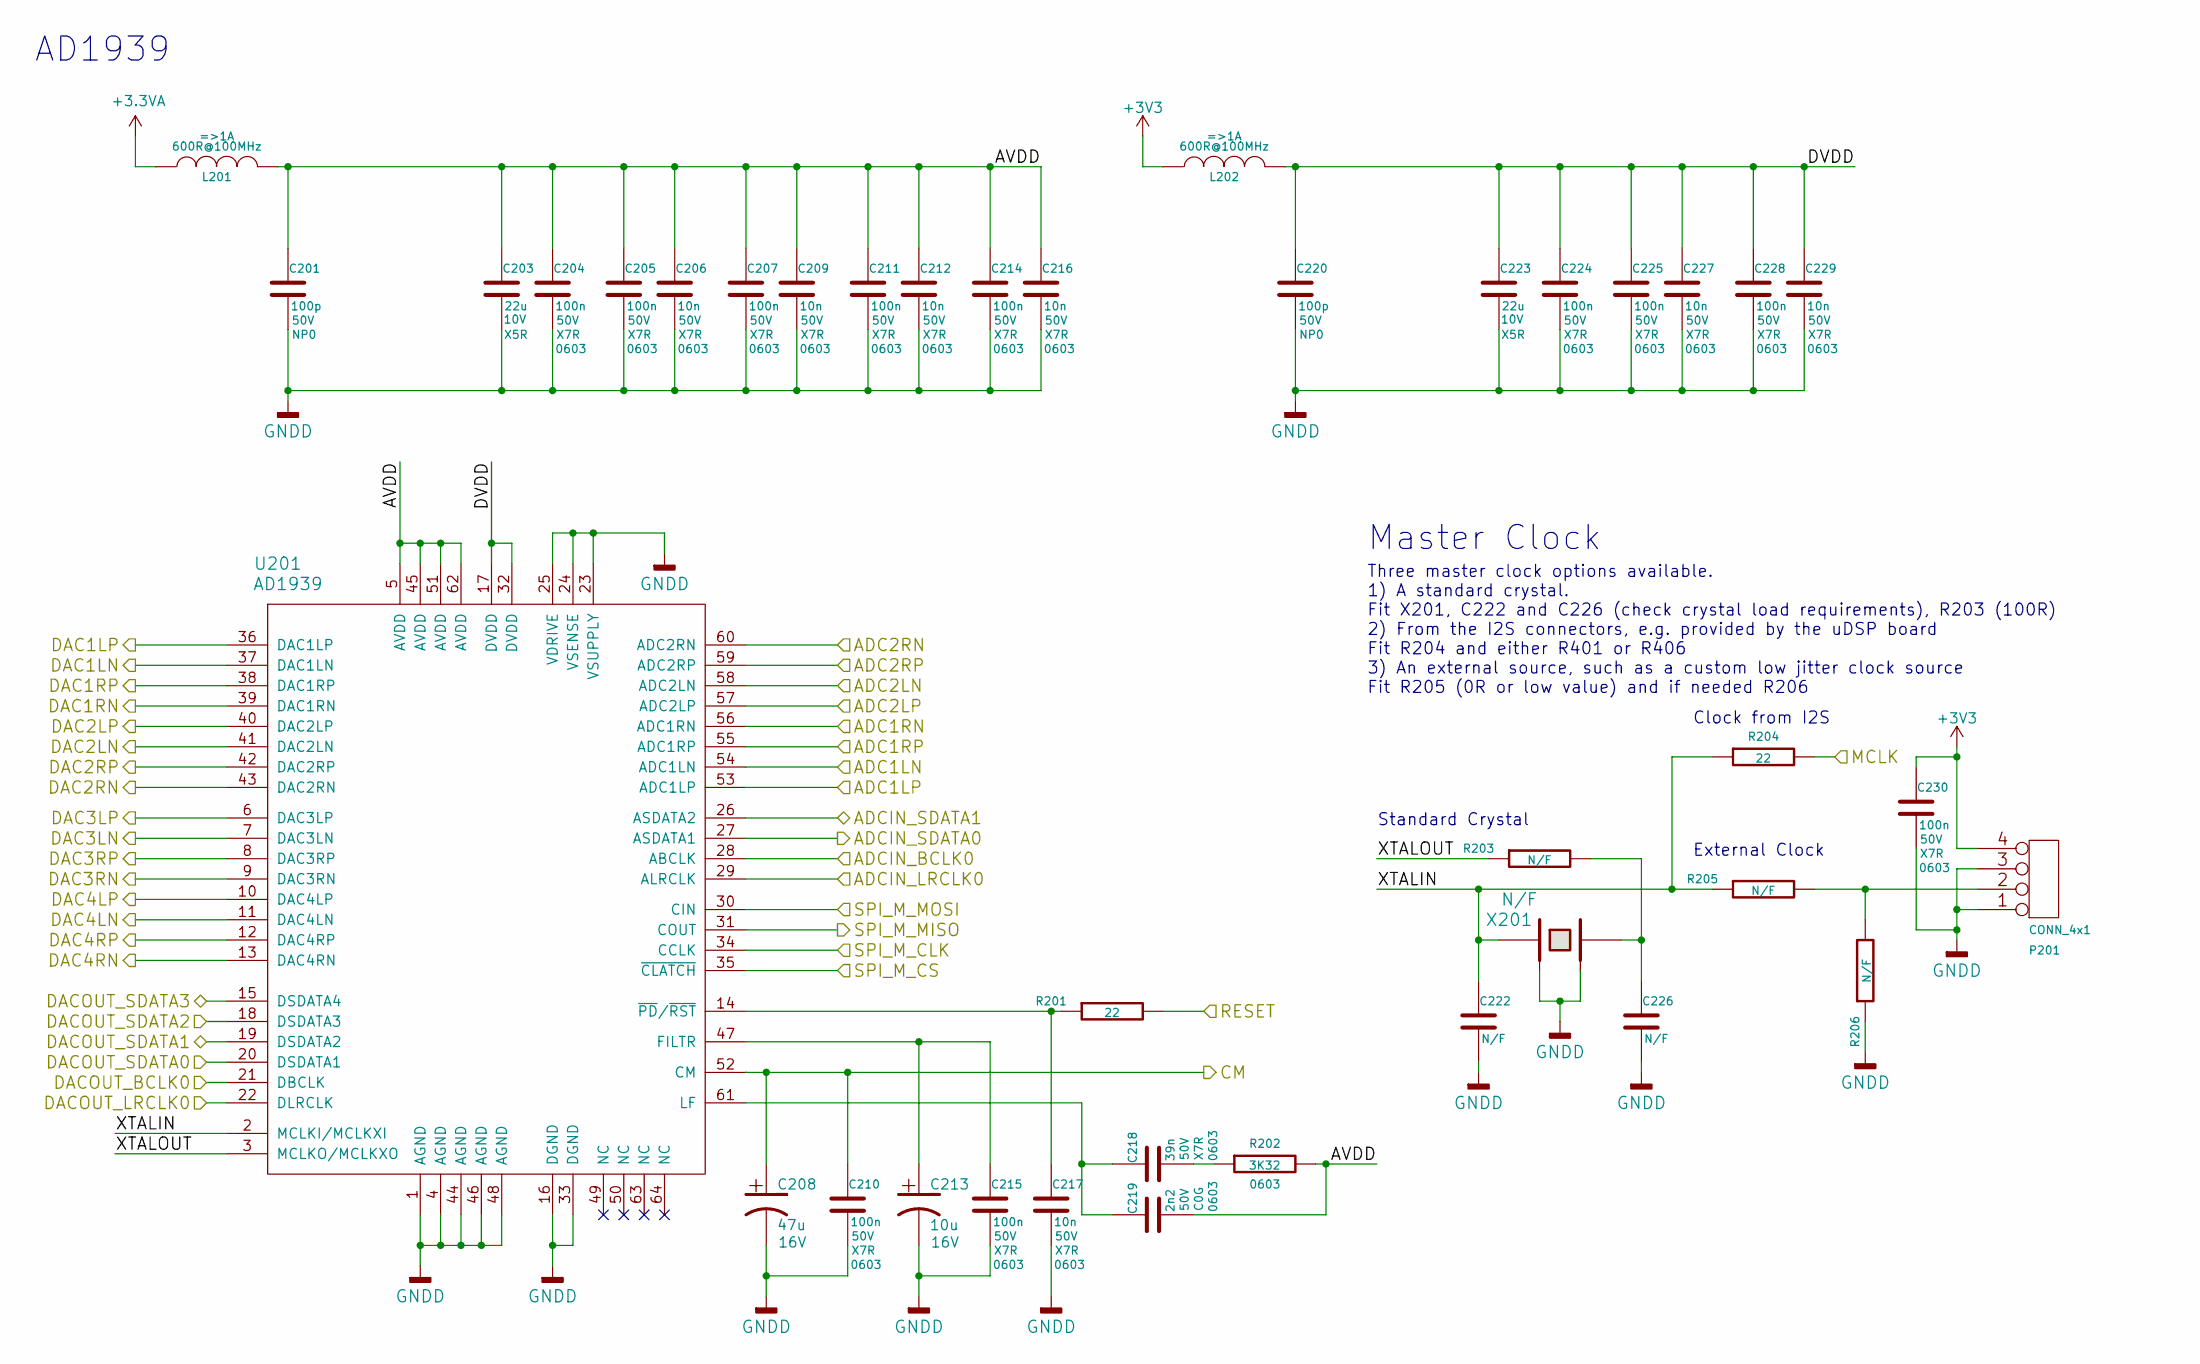
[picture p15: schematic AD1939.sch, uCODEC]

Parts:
C201, C220: 100p; SMD-0603; Voltage 50V; Tolerance 5%
C203, C223: 22u; SMD-0603; Voltage 10V; Tolerance 20%
C204, C205, C207, C210, C211, C214, C215, C224, C225, C228, C230: 100n; SMD-0603; Voltage 50V; Tolerance 10%
C206, C209, C212, C216, C217, C227, C229: 10n; SMD-0603; Voltage 50V; Tolerance 10%
C208: 47u; CAP-SMD-SIZE-D; Voltage 16V
C213: 10u; CAP-SMD-SIZE-B; Voltage 16V
C218: 39n; SMD-0603; Voltage 50V; Tolerance 10%
C219: 2n2; SMD-0603; Voltage 50V; Tolerance 5%
C222, C226: N/F; SMD-0603; Voltage 25V; Tolerance 5%
L201, L202: 600R@100MHz; SMD-0805
P201: CONN_4x1; CONN_SIL_4_1MM
R201, R204: 22; SMD-0603; Tolerance 1%
R202: 3K32; SMD-0603; Tolerance 1%
R203, R205, R206: N/F; SMD-0603; Tolerance 1%
U201: AD1939; IC-LQFP64
X201: N/F; XTAL_3.2x2.5_4PIN

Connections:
+3.3VA: L201.1; also elsewhere on the board
+3V3: C230.1, L202.1, P201.4; also elsewhere on the board
/AD1939/AVDD: C201.1, C203.1, C204.1, C205.1, C206.1, C207.1, C209.1, C211.1, C212.1, C214.1, C216.1, C219.2, L201.2, R202.2, U201.5 (AVDD), U201.45 (AVDD), U201.51 (AVDD), U201.62 (AVDD)
/AD1939/DVDD: C220.1, C223.1, C224.1, C225.1, C227.1, C228.1, C229.1, L202.2, U201.17 (DVDD), U201.32 (DVDD)
/AD1939/XTALIN: C222.1, R204.1, R205.1, U201.2 (MCLKI/MCLKXI), X201.1
/AD1939/XTALOUT: R203.1, U201.3 (MCLKO/MCLKXO)
/ADC1RN: U201.56 (ADC1RN); also elsewhere on the board
/ADC2LN: U201.58 (ADC2LN); also elsewhere on the board
/ADC2LP: U201.57 (ADC2LP); also elsewhere on the board
/ADC2RN: U201.60 (ADC2RN); also elsewhere on the board
/ADC2RP: U201.59 (ADC2RP); also elsewhere on the board
/CM: C208.1, C210.1, U201.52 (CM)
/CODEC_RST: R201.2; also elsewhere on the board
/DAC1LN: U201.37 (DAC1LN); also elsewhere on the board
/DAC1LP: U201.36 (DAC1LP); also elsewhere on the board
/DAC1RN: U201.39 (DAC1RN); also elsewhere on the board
/DAC1RP: U201.38 (DAC1RP); also elsewhere on the board
/DAC2LN: U201.41 (DAC2LN); also elsewhere on the board
/DAC2LP: U201.40 (DAC2LP); also elsewhere on the board
/DAC2RN: U201.43 (DAC2RN); also elsewhere on the board
/DAC2RP: U201.42 (DAC2RP); also elsewhere on the board
/DAC3LN: U201.7 (DAC3LN); also elsewhere on the board
/DAC3LP: U201.6 (DAC3LP); also elsewhere on the board
/DAC3RN: U201.9 (DAC3RN); also elsewhere on the board
/DAC3RP: U201.8 (DAC3RP); also elsewhere on the board
/DAC4LN: U201.11 (DAC4LN); also elsewhere on the board
/DAC4LP: U201.10 (DAC4LP); also elsewhere on the board
/DAC4RN: U201.13 (DAC4RN); also elsewhere on the board
/DAC4RP: U201.12 (DAC4RP); also elsewhere on the board
/IN_BCLK0: U201.28 (ABCLK); also elsewhere on the board
/IN_LRCLK0: U201.29 (ALRCLK); also elsewhere on the board
/IN_SDATA0: U201.27 (ASDATA1); also elsewhere on the board
/IN_SDATA1: U201.26 (ASDATA2); also elsewhere on the board
/MCLK: R204.2; also elsewhere on the board
/OUT_BCLK0: U201.21 (DBCLK); also elsewhere on the board
/OUT_LRCLK0: U201.22 (DLRCLK); also elsewhere on the board
/OUT_SDATA0: U201.20 (DSDATA1); also elsewhere on the board
/OUT_SDATA1: U201.19 (DSDATA2); also elsewhere on the board
/OUT_SDATA2: U201.18 (DSDATA3); also elsewhere on the board
/OUT_SDATA3: U201.15 (DSDATA4); also elsewhere on the board
/SPI_M_CLK: U201.34 (CCLK); also elsewhere on the board
/SPI_M_CS: U201.35 (~CLATCH); also elsewhere on the board
/SPI_M_MISO: U201.31 (COUT); also elsewhere on the board
/SPI_M_MOSI: U201.30 (CIN); also elsewhere on the board
unnamed: C213.1, C215.1, U201.47 (FILTR)
unnamed: C217.1, R201.1, U201.14 (~PD~/~RST)
unnamed: C218.1, C219.1, U201.61 (LF)
unnamed: C218.2, R202.1
unnamed: C226.1, R203.2, X201.3
unnamed: P201.2, R205.2, R206.2

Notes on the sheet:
Master Clock
Standard Crystal
External Clock
AD1939
Clock from I2S
Three master clock options available. 1) A standard crystal. Fit X201, C222 and C226 (check crystal load requirements), R203 (100R) 2) From the I2S connectors, e.g. provided by the uDSP board Fit R204 and either R401 or R406 3) An external source, such as a custom low jitter clock source Fit R205 (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

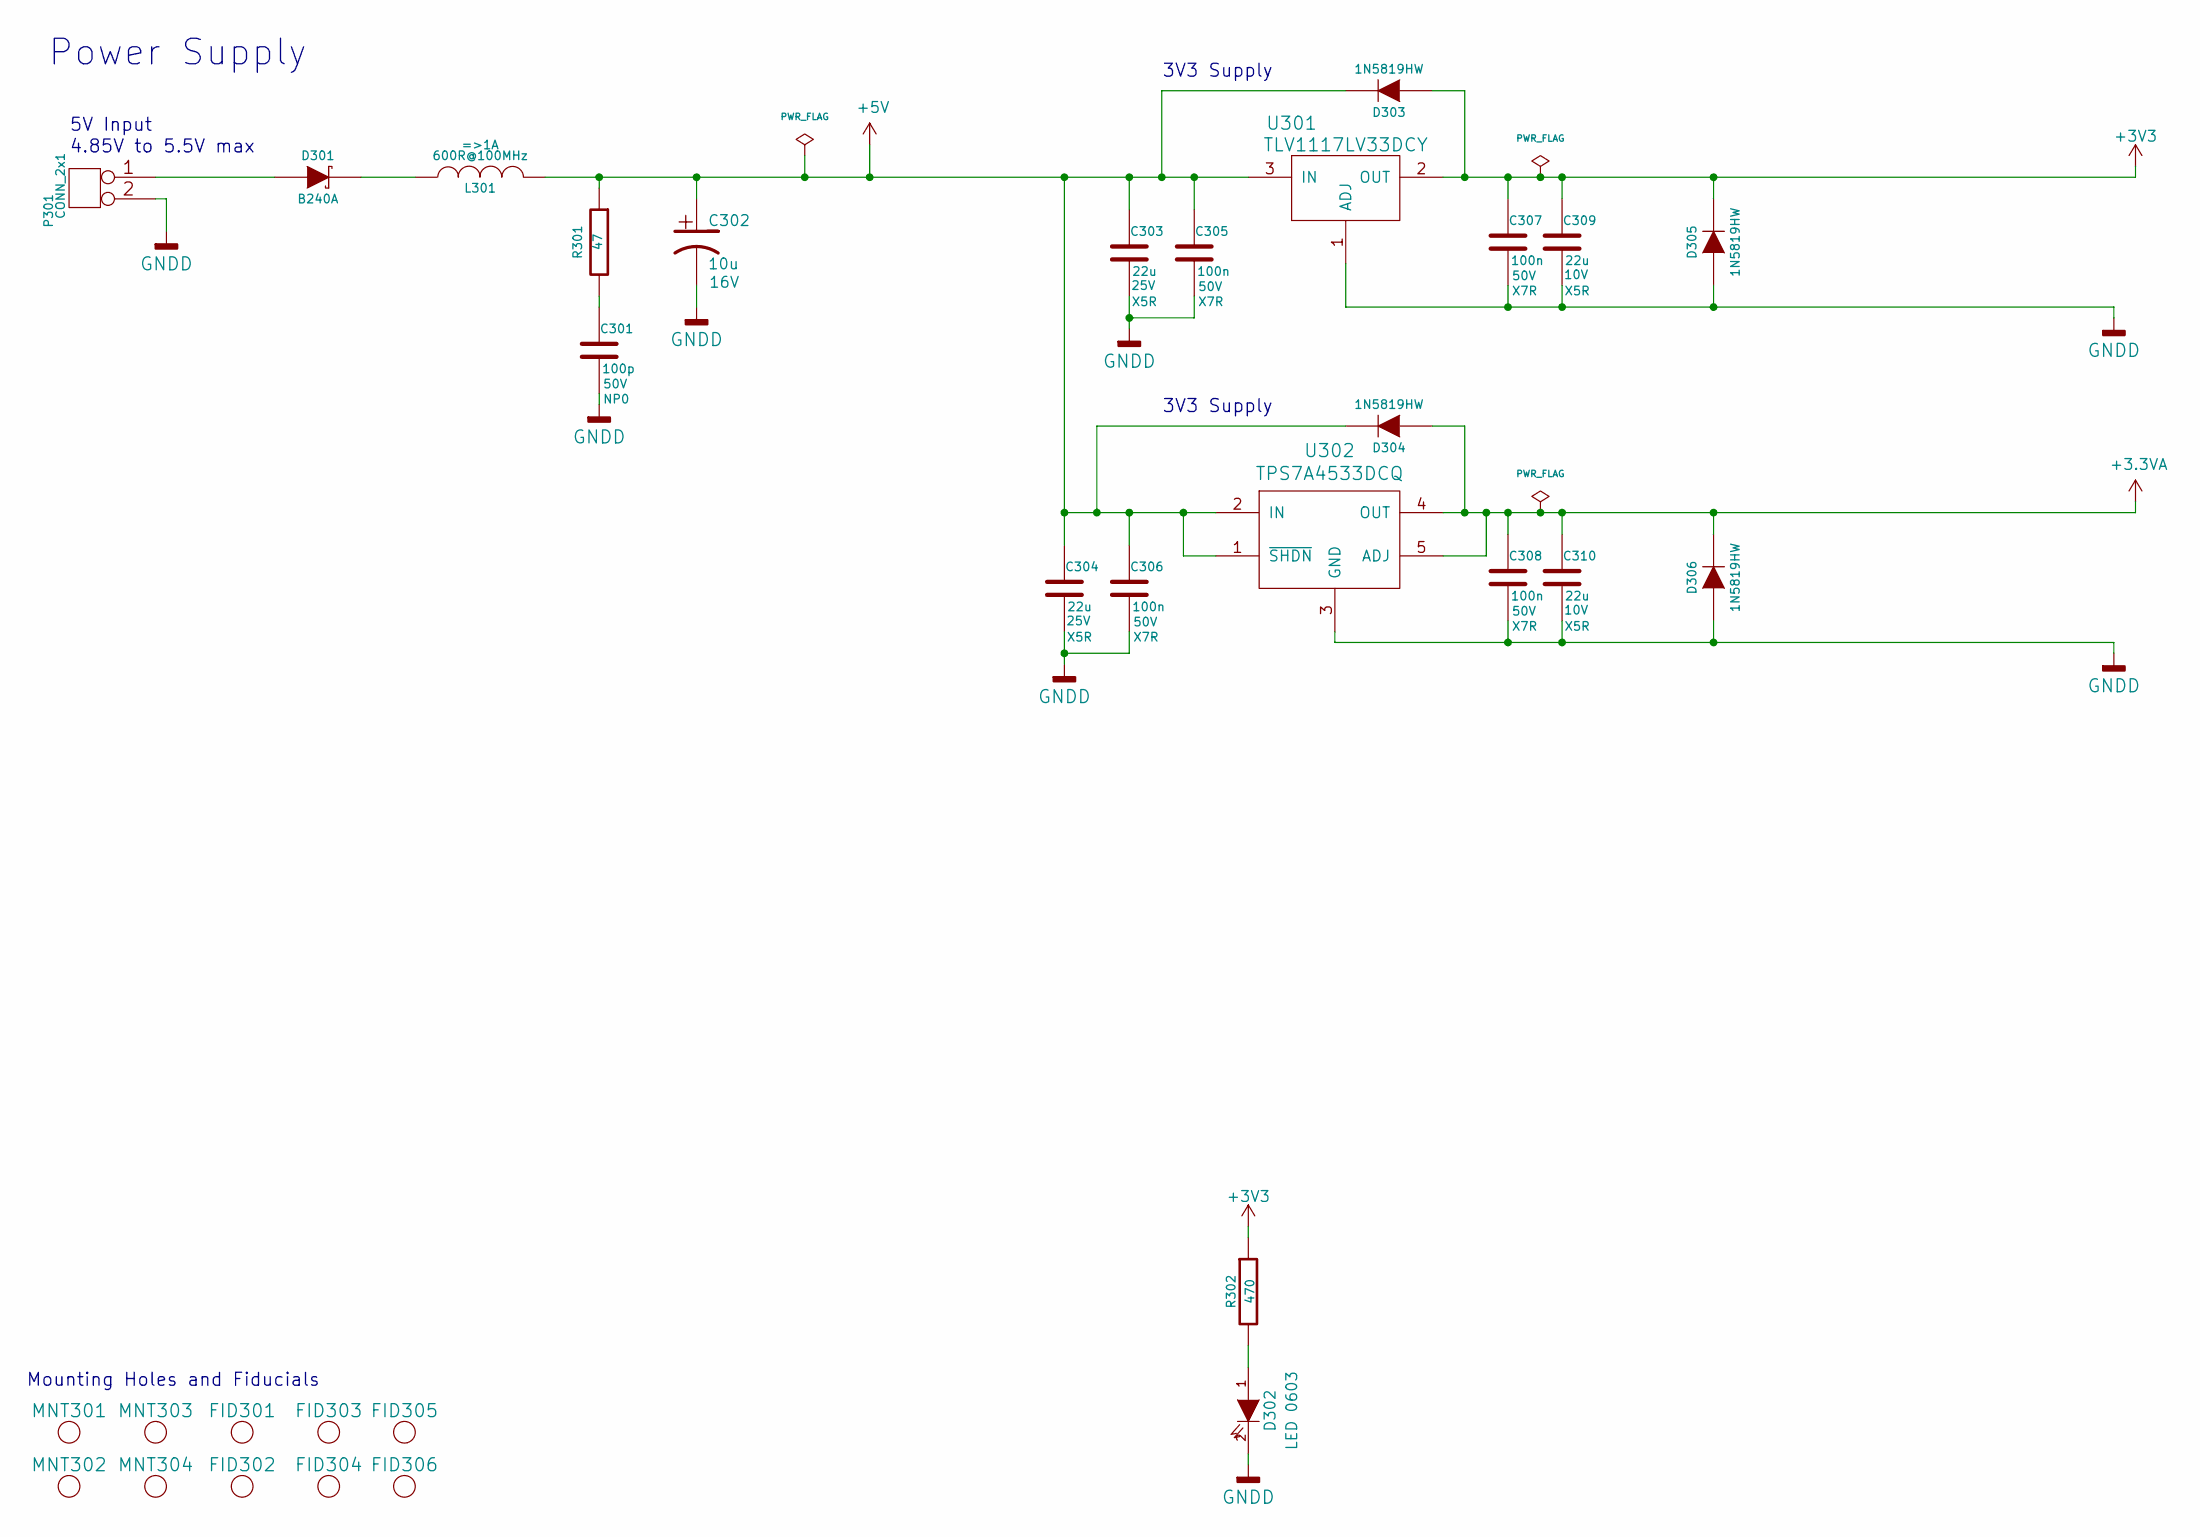
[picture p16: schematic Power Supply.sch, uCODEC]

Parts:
C301: 100p; SMD-0603; Voltage 50V; Tolerance 5%
C302: 10u; CAP-SMD-SIZE-B; Voltage 16V
C303, C304: 22u; SMD-0805; Voltage 25V; Tolerance 20%
C305, C306, C307, C308: 100n; SMD-0603; Voltage 50V; Tolerance 10%
C309, C310: 22u; SMD-0603; Voltage 10V; Tolerance 20%
D301: B240A; DIODE-SMA
D302: LED 0603; SMD-0603-LED
D303, D304, D305, D306: 1N5819HW; DIODE-SOD-123
FID301, FID302, FID303, FID304, FID305, FID306: MNT_HOLE; FID-1MM-2MM
L301: 600R@100MHz; SMD-0805
MNT301, MNT302, MNT303, MNT304: MNT_HOLE; MNT_HOLE_3.2mm
P301: CONN_2x1; CONN-2WAY-2.54mm-3.81mm-SPACING
R301: 47; SMD-0603; Tolerance 1%
R302: 470; SMD-0603; Tolerance 1%
U301: TLV1117LV33DCY; IC-SOT-223
U302: TPS7A4533DCQ; IC-SOT223-6

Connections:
+3.3VA: C308.1, C310.1, D304.1 (A), D306.2 (K), U302.4 (OUT), U302.5 (ADJ); also elsewhere on the board
+3V3: C307.1, C309.1, D303.1 (A), D305.2 (K), R302.1, U301.2 (OUT); also elsewhere on the board
+5V: C302.1, C303.1, C304.1, C305.1, C306.1, D303.2 (K), D304.2 (K), L301.2, R301.1, U301.3 (IN), U302.1 (~SHDN), U302.2 (IN)
unnamed: C301.1, R301.2
unnamed: D301.1 (A), P301.1
unnamed: D301.2 (K), L301.1
unnamed: D302.1 (A), R302.2

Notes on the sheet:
Power Supply
5V Input
3V3 Supply
Mounting Holes and Fiducials
4.85V to 5.5V max

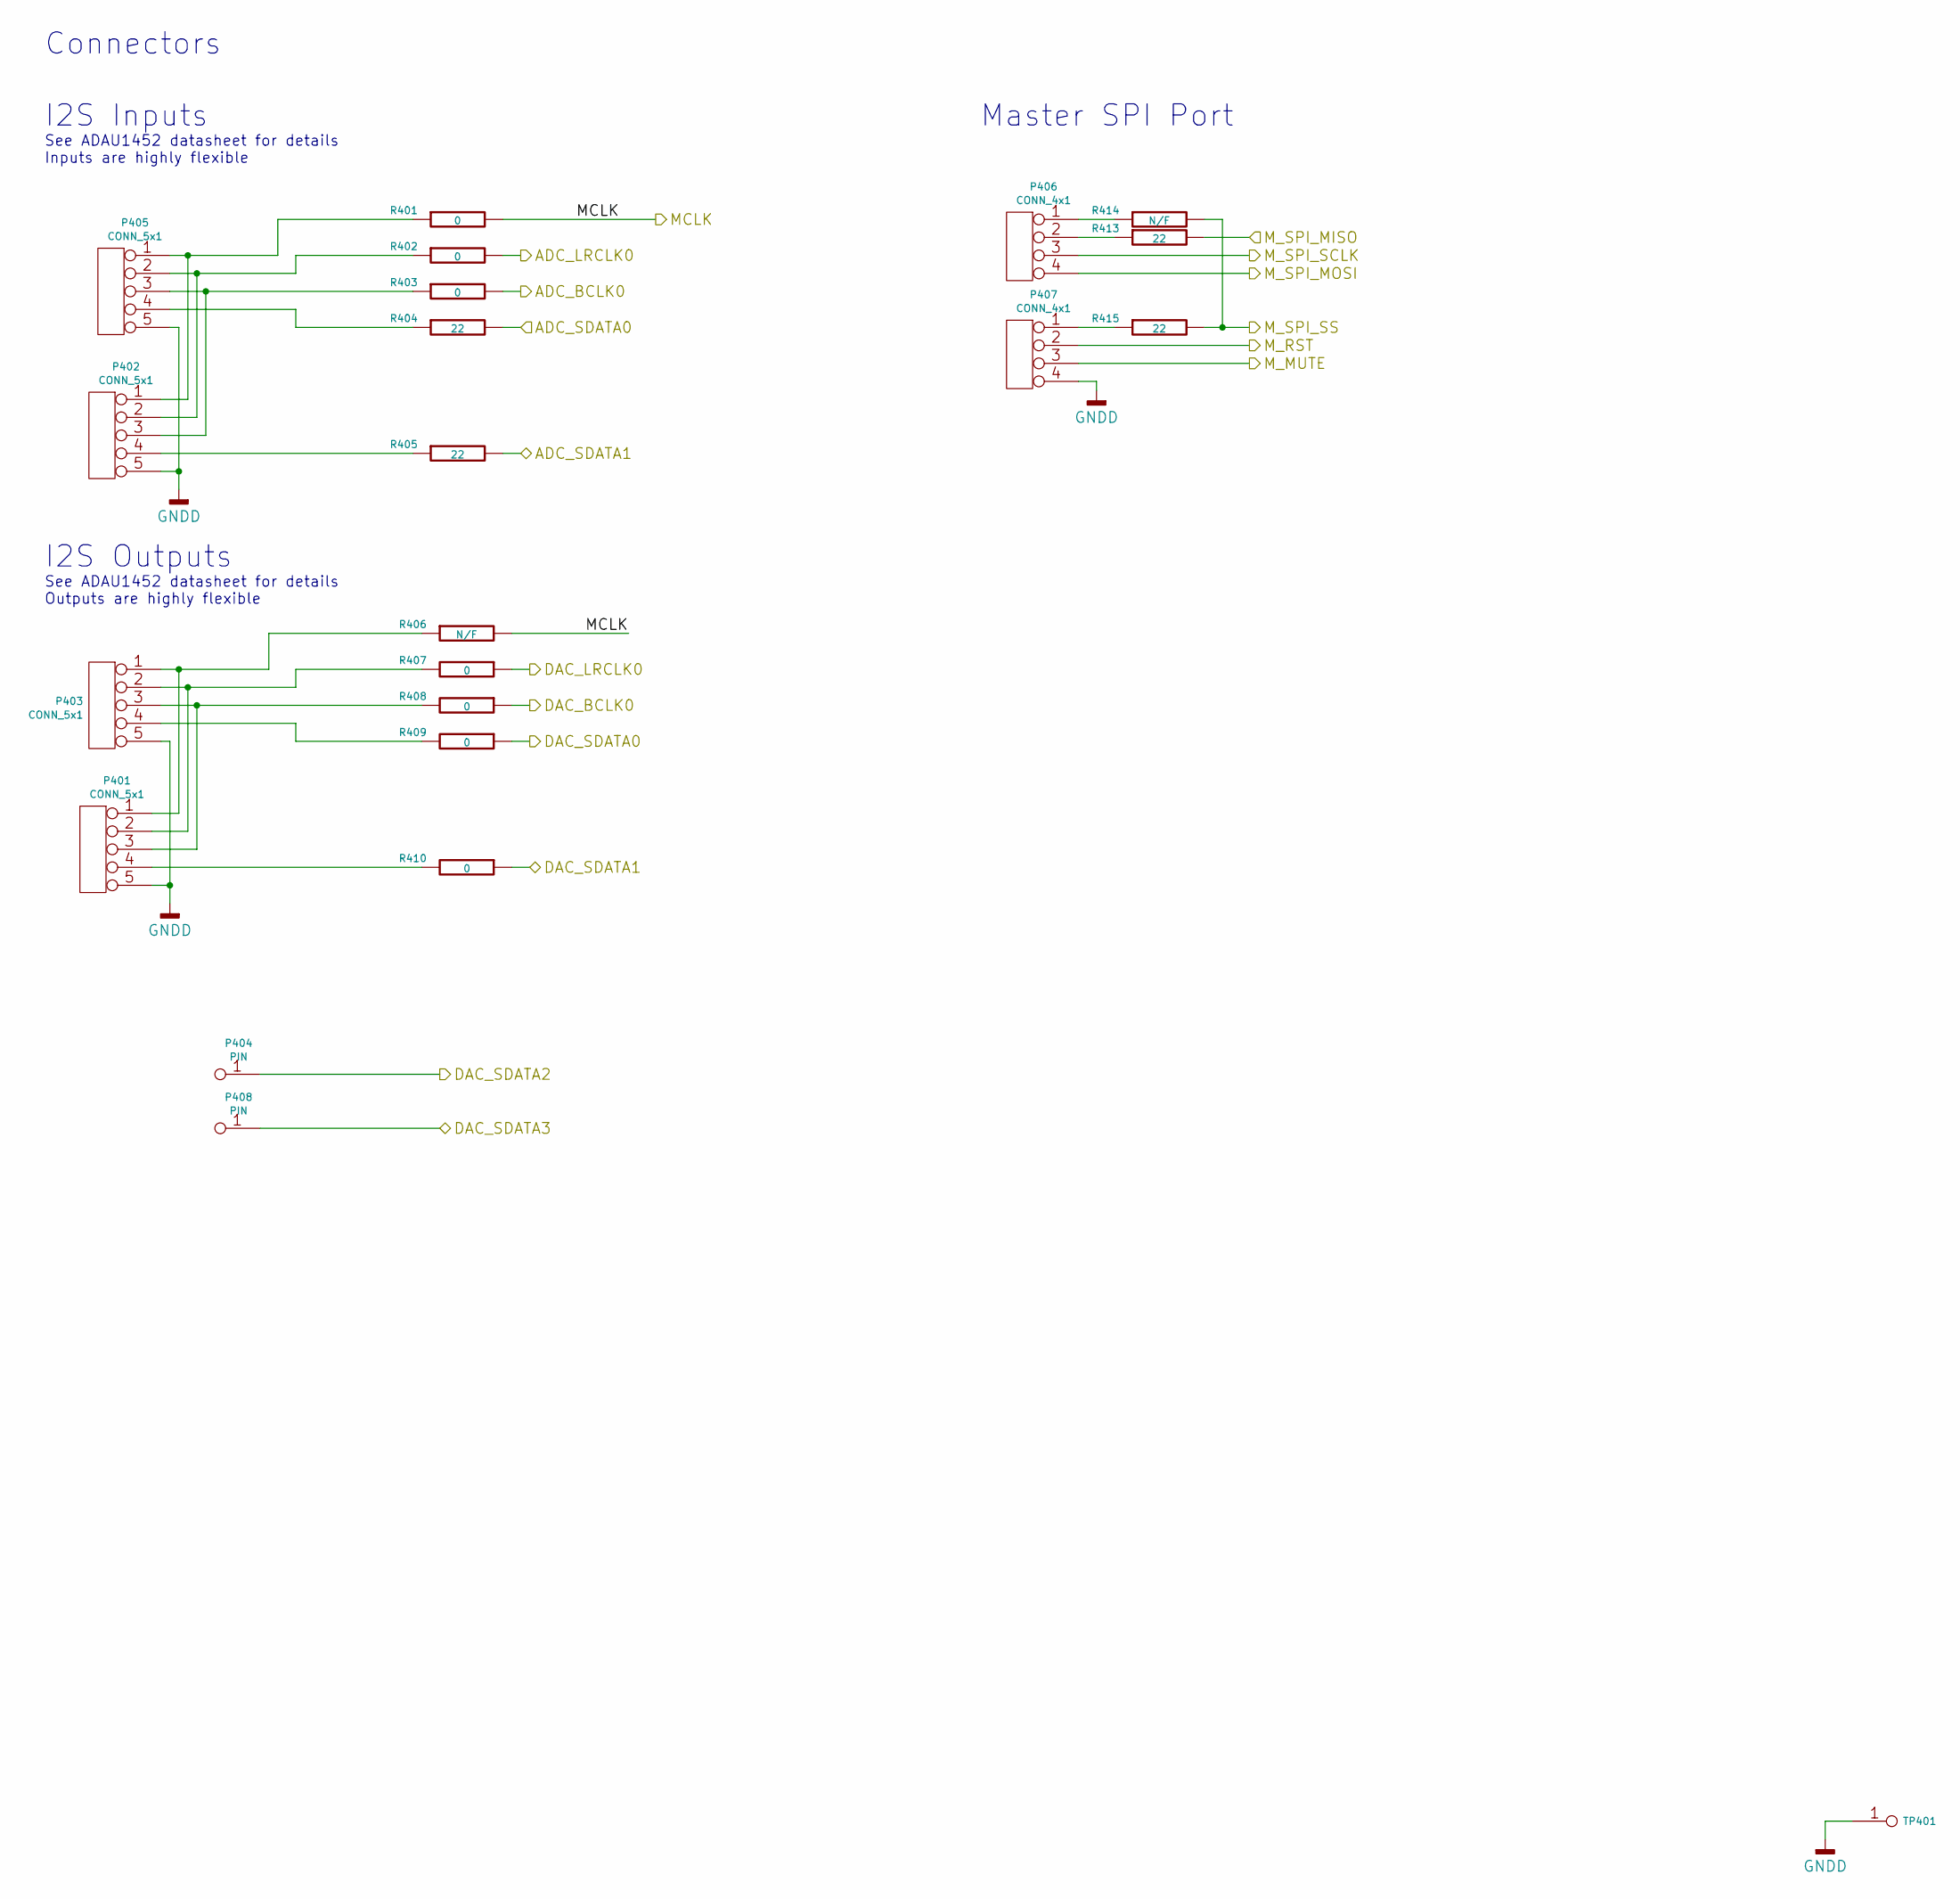
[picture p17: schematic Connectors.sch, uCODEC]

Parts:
P401, P402, P403, P405: CONN_5x1; CONN_SIL_5_1MM
P404, P408: PIN; TP-1mm
P406, P407: CONN_4x1; CONN_SIL_4_1MM
R401, R402, R403, R407, R408, R409, R410: 0; SMD-0603; Tolerance 1%
R404, R405, R413, R415: 22; SMD-0603; Tolerance 1%
R406, R414: N/F; SMD-0603; Tolerance 1%
TP401: PIN; TP-TH-1mm

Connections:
/GLB_RESET: P407.2; also elsewhere on the board
/IN_BCLK0: R403.2; also elsewhere on the board
/IN_LRCLK0: R402.2; also elsewhere on the board
/IN_SDATA0: R404.2; also elsewhere on the board
/IN_SDATA1: R405.2; also elsewhere on the board
/MCLK: R401.2, R406.2; also elsewhere on the board
/OUT_BCLK0: R408.1; also elsewhere on the board
/OUT_LRCLK0: R407.1; also elsewhere on the board
/OUT_SDATA0: R409.1; also elsewhere on the board
/OUT_SDATA1: R410.1; also elsewhere on the board
/OUT_SDATA2: P404.1; also elsewhere on the board
/OUT_SDATA3: P408.1; also elsewhere on the board
/SPI_M_CLK: P406.3; also elsewhere on the board
/SPI_M_CS: R414.2, R415.2; also elsewhere on the board
/SPI_M_MISO: R413.2; also elsewhere on the board
/SPI_M_MOSI: P406.4; also elsewhere on the board
unnamed: P401.1, P403.1, R406.1
unnamed: P401.2, P403.2, R407.2
unnamed: P401.3, P403.3, R408.2
unnamed: P401.4, R410.2
unnamed: P402.1, P405.1, R401.1
unnamed: P402.2, P405.2, R402.1
unnamed: P402.3, P405.3, R403.1
unnamed: P402.4, R405.1
unnamed: P403.4, R409.2
unnamed: P405.4, R404.1
unnamed: P406.1, R414.1
unnamed: P406.2, R413.1
unnamed: P407.1, R415.1

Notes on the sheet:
I2S Inputs
See ADAU1452 datasheet for details Inputs are highly flexible
I2S Outputs
See ADAU1452 datasheet for details Outputs are highly flexible
Master SPI Port
Connectors

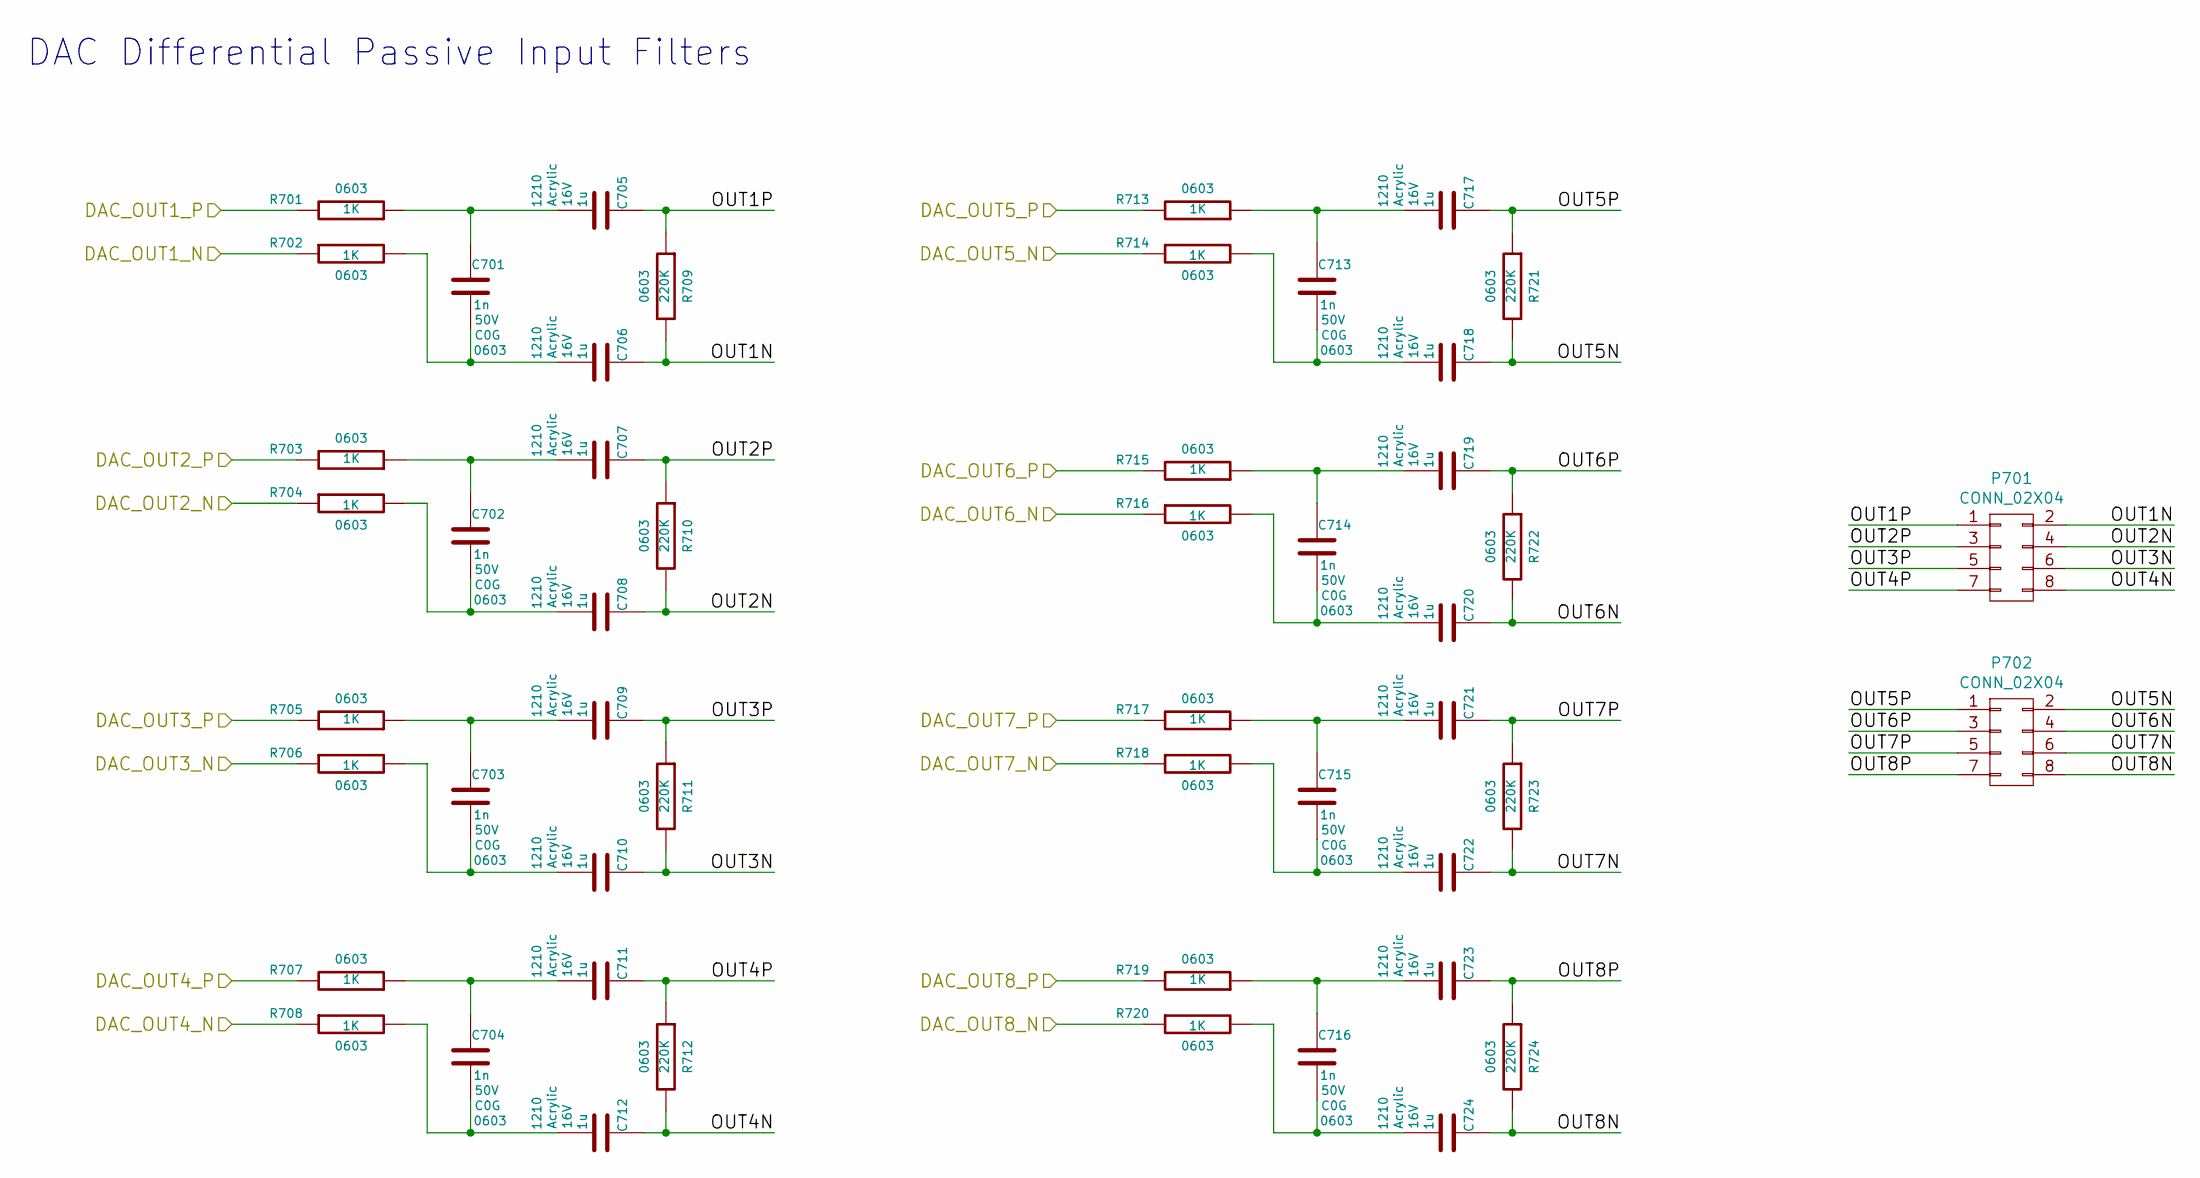
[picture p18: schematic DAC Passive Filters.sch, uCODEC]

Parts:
C701, C702, C703, C704, C713, C714, C715, C716: 1n; SMD-0603; Voltage 50V; Tolerance 5%
C705, C706, C707, C708, C709, C710, C711, C712, C717, C718, C719, C720, C721, C722, C723, C724: 1u; SMD-1210; Voltage 16V; Tolerance 20%
P701, P702: CONN_02X04; CONN_DIL_2X04
R701, R702, R703, R704, R705, R706, R707, R708, R713, R714, R715, R716, R717, R718, R719, R720: 1K; SMD-0603; Tolerance 1%
R709, R710, R711, R712, R721, R722, R723, R724: 220K; SMD-0603; Tolerance 1%

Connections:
/DAC1LN: R702.1; also elsewhere on the board
/DAC1LP: R701.2; also elsewhere on the board
/DAC1RN: R704.1; also elsewhere on the board
/DAC1RP: R703.2; also elsewhere on the board
/DAC2LN: R706.1; also elsewhere on the board
/DAC2LP: R705.2; also elsewhere on the board
/DAC2RN: R708.1; also elsewhere on the board
/DAC2RP: R707.2; also elsewhere on the board
/DAC3LN: R714.1; also elsewhere on the board
/DAC3LP: R713.2; also elsewhere on the board
/DAC3RN: R716.1; also elsewhere on the board
/DAC3RP: R715.2; also elsewhere on the board
/DAC4LN: R718.1; also elsewhere on the board
/DAC4LP: R717.2; also elsewhere on the board
/DAC4RN: R720.1; also elsewhere on the board
/DAC4RP: R719.2; also elsewhere on the board
/DAC Passive Filters/OUT1N: C706.1, P701.2, R709.2
/DAC Passive Filters/OUT1P: C705.1, P701.1, R709.1
/DAC Passive Filters/OUT2N: C708.1, P701.4, R710.2
/DAC Passive Filters/OUT2P: C707.1, P701.3, R710.1
/DAC Passive Filters/OUT3N: C710.1, P701.6, R711.2
/DAC Passive Filters/OUT3P: C709.1, P701.5, R711.1
/DAC Passive Filters/OUT4N: C712.1, P701.8, R712.2
/DAC Passive Filters/OUT4P: C711.1, P701.7, R712.1
/DAC Passive Filters/OUT5N: C718.1, P702.2, R721.2
/DAC Passive Filters/OUT5P: C717.1, P702.1, R721.1
/DAC Passive Filters/OUT6N: C720.1, P702.4, R722.2
/DAC Passive Filters/OUT6P: C719.1, P702.3, R722.1
/DAC Passive Filters/OUT7N: C722.1, P702.6, R723.2
/DAC Passive Filters/OUT7P: C721.1, P702.5, R723.1
/DAC Passive Filters/OUT8N: C724.1, P702.8, R724.2
/DAC Passive Filters/OUT8P: C723.1, P702.7, R724.1
unnamed: C701.1, C705.2, R701.1
unnamed: C701.2, C706.2, R702.2
unnamed: C702.1, C707.2, R703.1
unnamed: C702.2, C708.2, R704.2
unnamed: C703.1, C709.2, R705.1
unnamed: C703.2, C710.2, R706.2
unnamed: C704.1, C711.2, R707.1
unnamed: C704.2, C712.2, R708.2
unnamed: C713.1, C717.2, R713.1
unnamed: C713.2, C718.2, R714.2
unnamed: C714.1, C719.2, R715.1
unnamed: C714.2, C720.2, R716.2
unnamed: C715.1, C721.2, R717.1
unnamed: C715.2, C722.2, R718.2
unnamed: C716.1, C723.2, R719.1
unnamed: C716.2, C724.2, R720.2

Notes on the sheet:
DAC Differential Passive Input Filters

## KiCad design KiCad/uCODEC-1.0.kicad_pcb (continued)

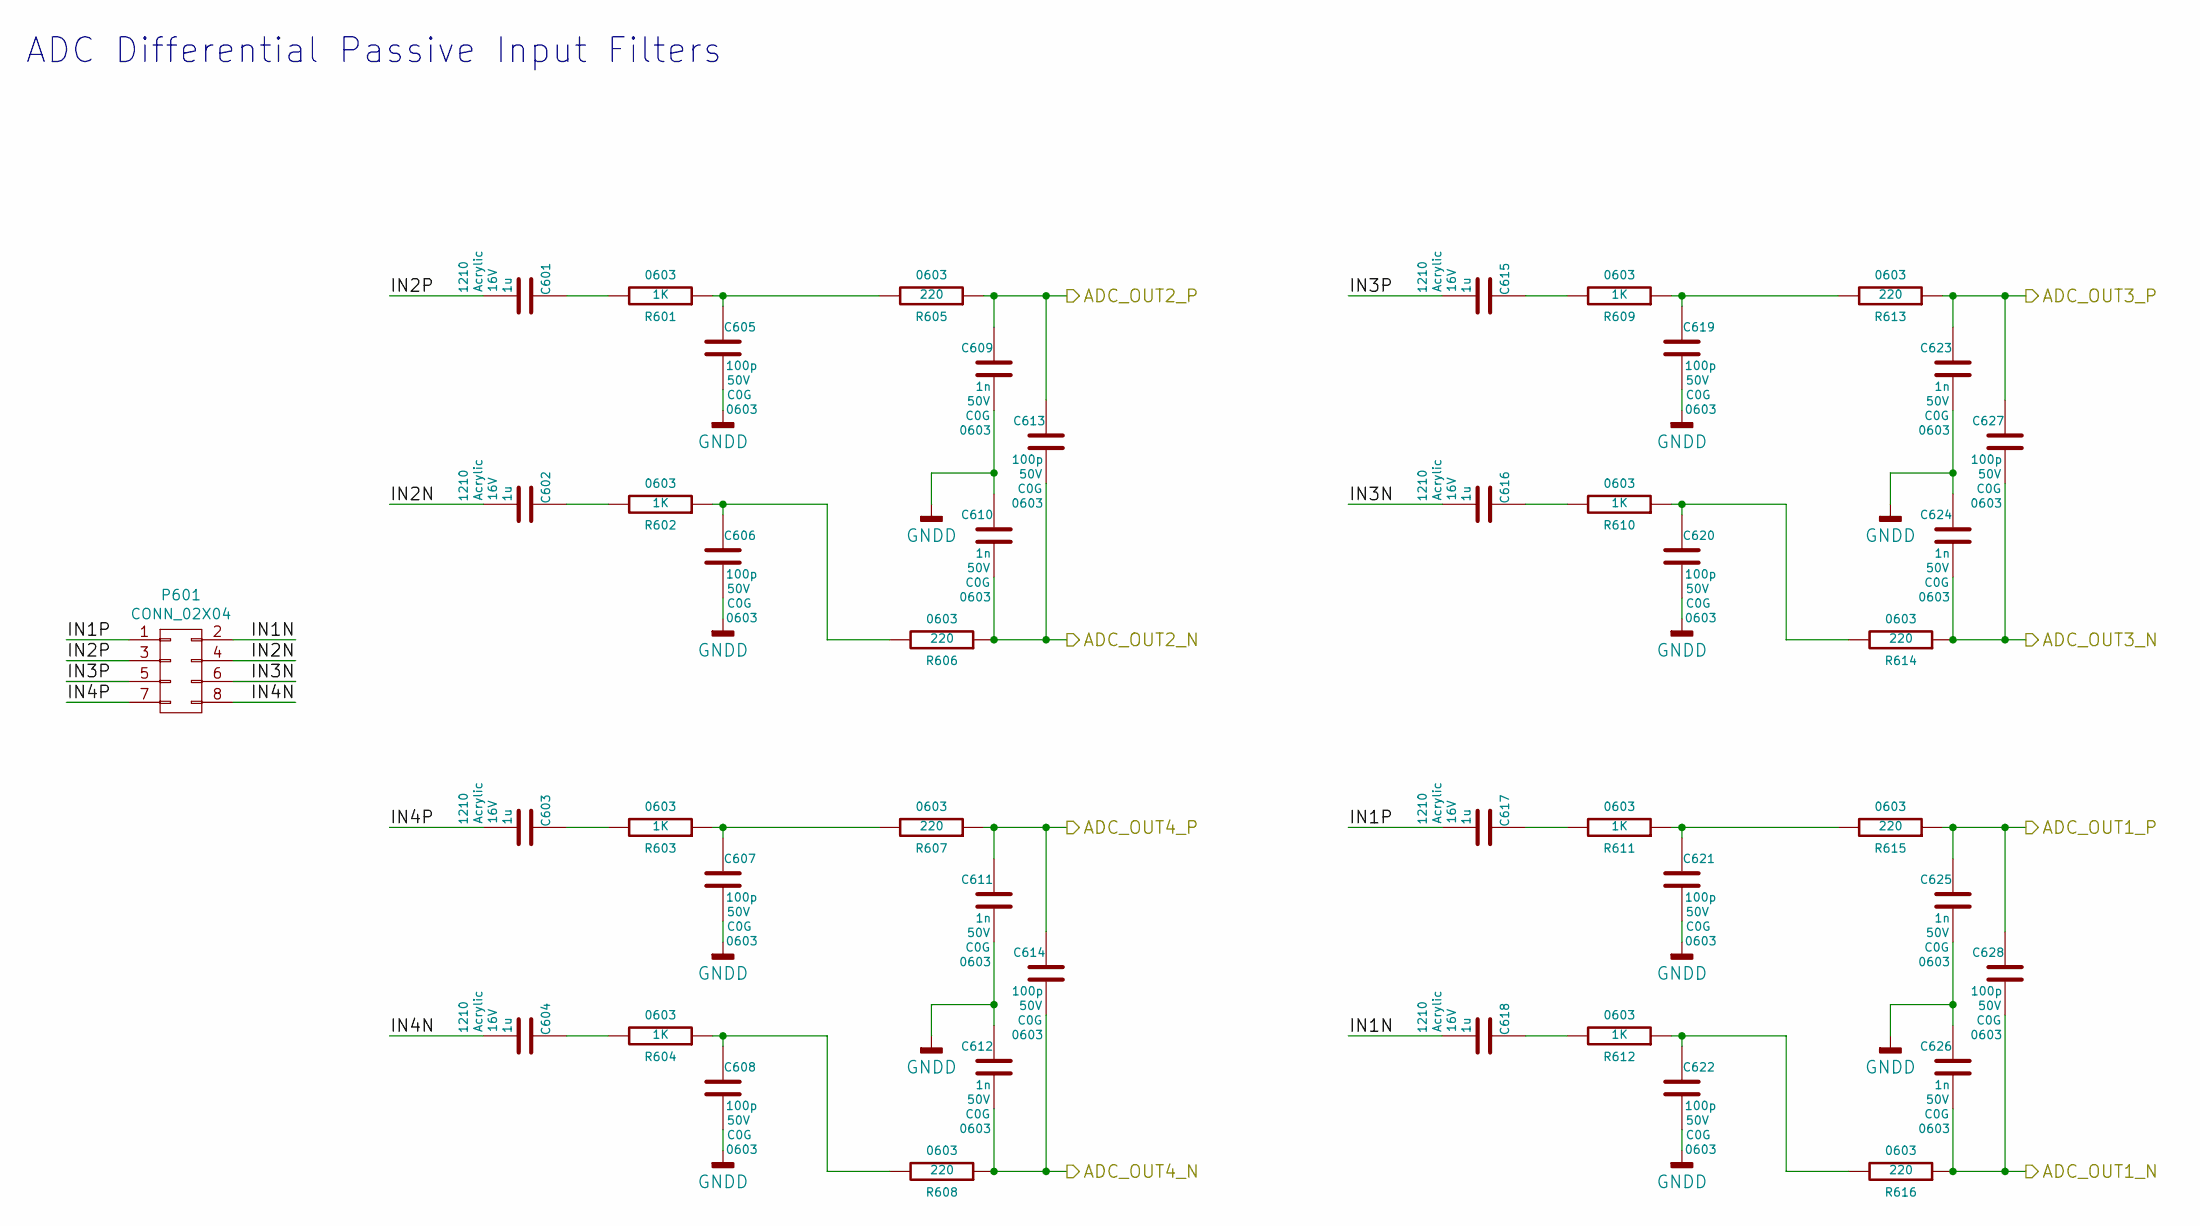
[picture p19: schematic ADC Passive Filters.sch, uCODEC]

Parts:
C601, C602, C604, C615, C616, C617, C618: 1u; SMD-1210; Voltage 16V; Tolerance 20%
C603, C607, C608, C609, C614, C619, C620, C621, C622, C627, C628: 100p; SMD-0603; Voltage 50V; Tolerance 5%
C605, C606, C611, C612, C623, C624, C625, C626: 1n; SMD-0603; Voltage 50V; Tolerance 5%
P601: CONN_02X04; CONN_DIL_2X04
R601, R602, R603, R604, R609, R610, R611, R612: 1K; SMD-0603; Tolerance 1%
R607, R608, R613, R614, R615, R616: 220; SMD-0603; Tolerance 1%

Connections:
/ADC2LN: C624.2, C627.2, R614.1; also elsewhere on the board
/ADC2LP: C623.1, C627.1, R613.1; also elsewhere on the board
/ADC2RN: C612.2, C614.2, R608.1; also elsewhere on the board
/ADC2RP: C611.1, C614.1, R607.1; also elsewhere on the board
/ADC Passive Filters/IN1N: C618.2, P601.2
/ADC Passive Filters/IN1P: C617.2, P601.1
/ADC Passive Filters/IN2N: C602.2, P601.4
/ADC Passive Filters/IN2P: C601.2, P601.3
/ADC Passive Filters/IN3N: C616.2, P601.6
/ADC Passive Filters/IN3P: C615.2, P601.5
/ADC Passive Filters/IN4N: C604.2, P601.8
unnamed: C601.1, R601.2
unnamed: C602.1, R602.2
unnamed: C604.1, R604.2
unnamed: C607.1, R603.1, R607.2
unnamed: C608.1, R604.1, R608.2
unnamed: C615.1, R609.2
unnamed: C616.1, R610.2
unnamed: C617.1, R611.2
unnamed: C618.1, R612.2
unnamed: C619.1, R609.1, R613.2
unnamed: C620.1, R610.1, R614.2

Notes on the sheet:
ADC Differential Passive Input Filters

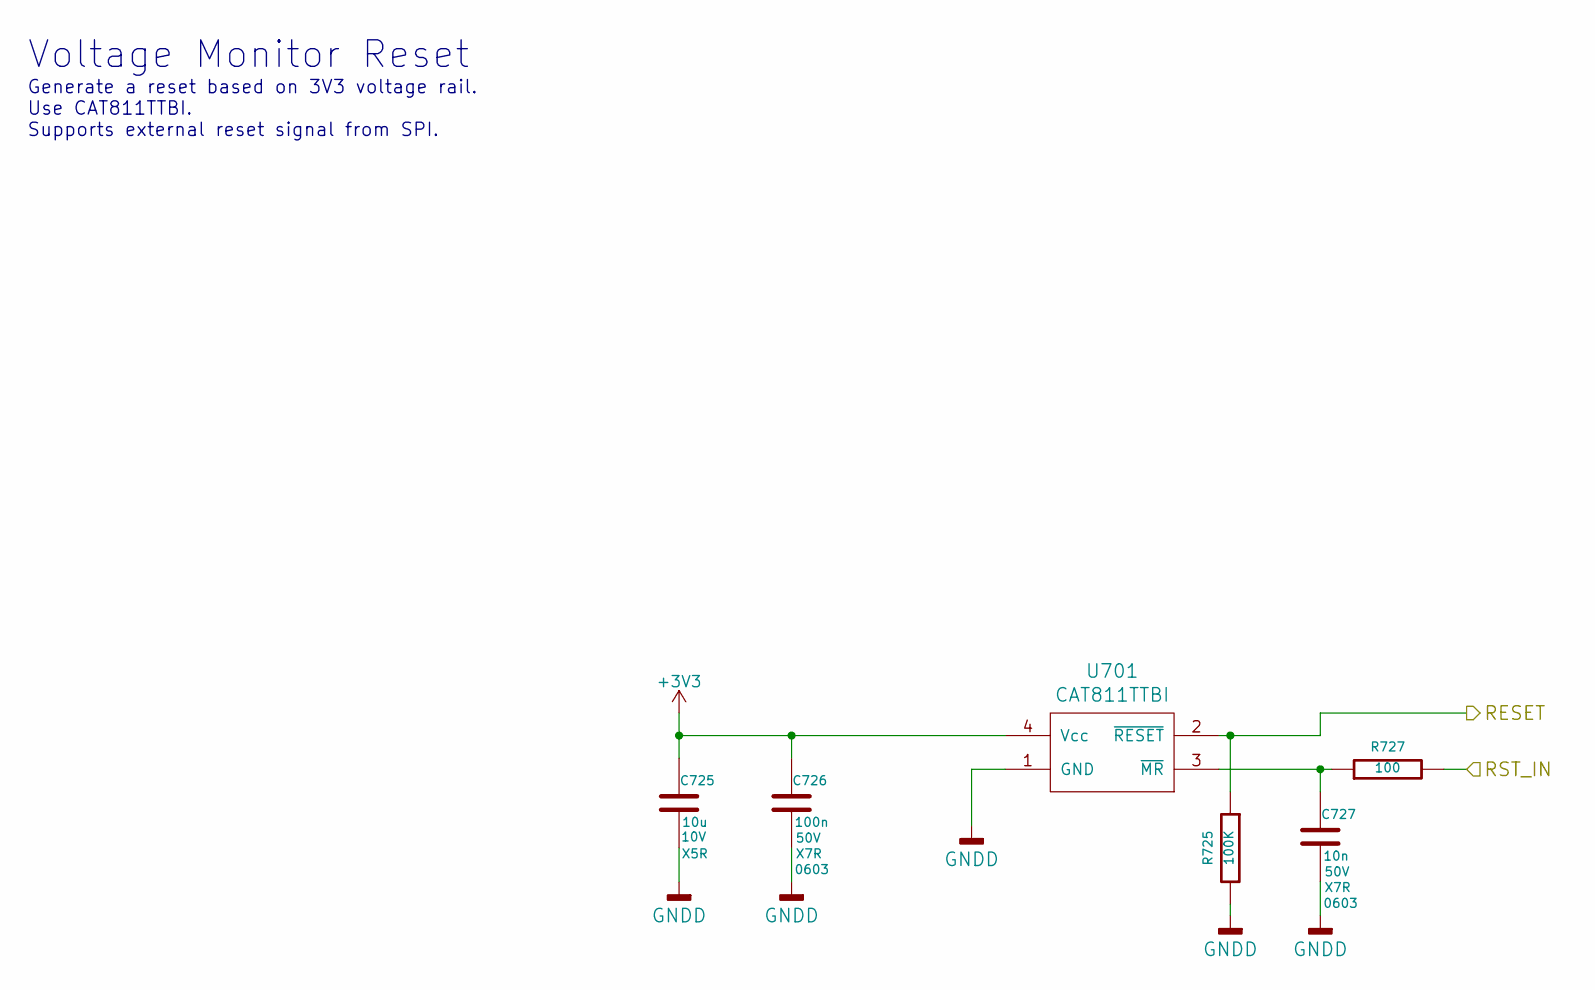
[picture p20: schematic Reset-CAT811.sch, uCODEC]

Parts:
C725: 10u; SMD-0603; Voltage 10V; Tolerance 20%
C726: 100n; SMD-0603; Voltage 50V; Tolerance 10%
C727: 10n; SMD-0603; Voltage 50V; Tolerance 10%
R725: 100K; SMD-0603; Tolerance 1%
R727: 100; SMD-0603; Tolerance 1%
U701: CAT811TTBI; IC-SOT143

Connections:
+3V3: C725.1, C726.1, U701.4 (Vcc); also elsewhere on the board
/CODEC_RST: R725.1, U701.2 (~RESET); also elsewhere on the board
/GLB_RESET: R727.2; also elsewhere on the board
unnamed: C727.1, R727.1, U701.3 (~MR)

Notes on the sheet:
Generate a reset based on 3V3 voltage rail. Use CAT811TTBI. Supports external reset signal from SPI.
Voltage Monitor Reset

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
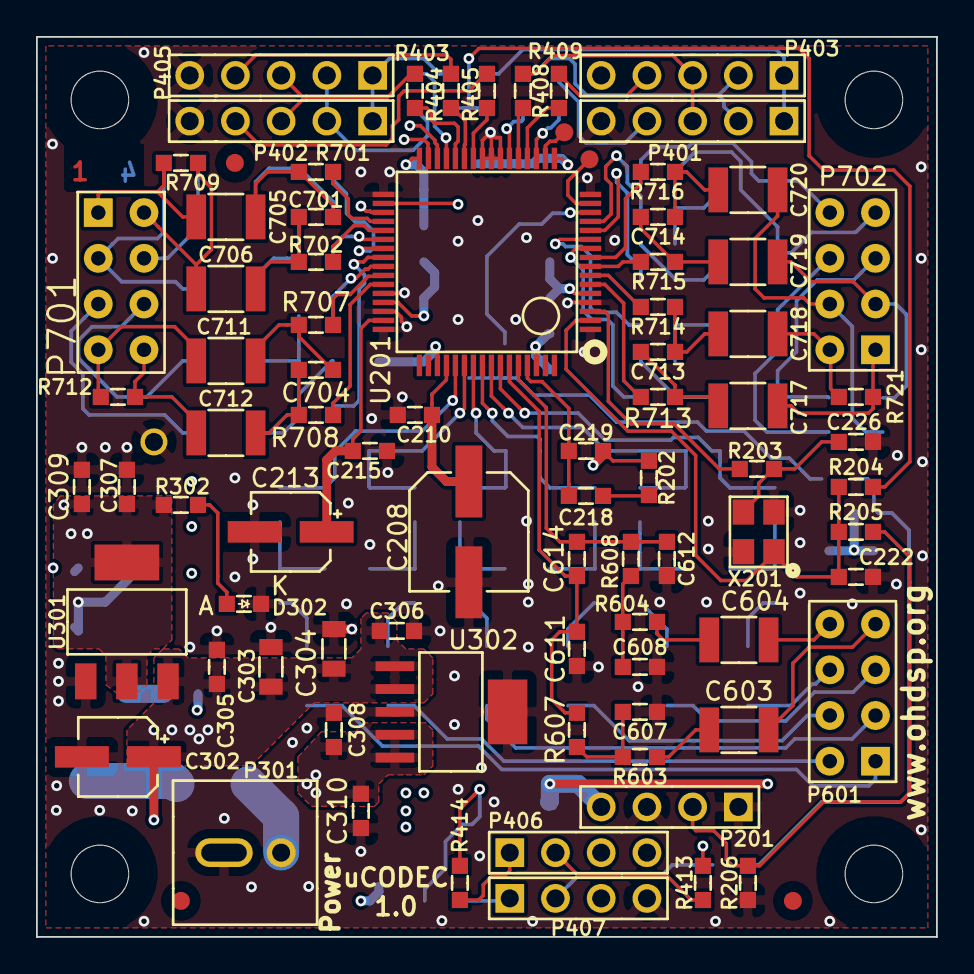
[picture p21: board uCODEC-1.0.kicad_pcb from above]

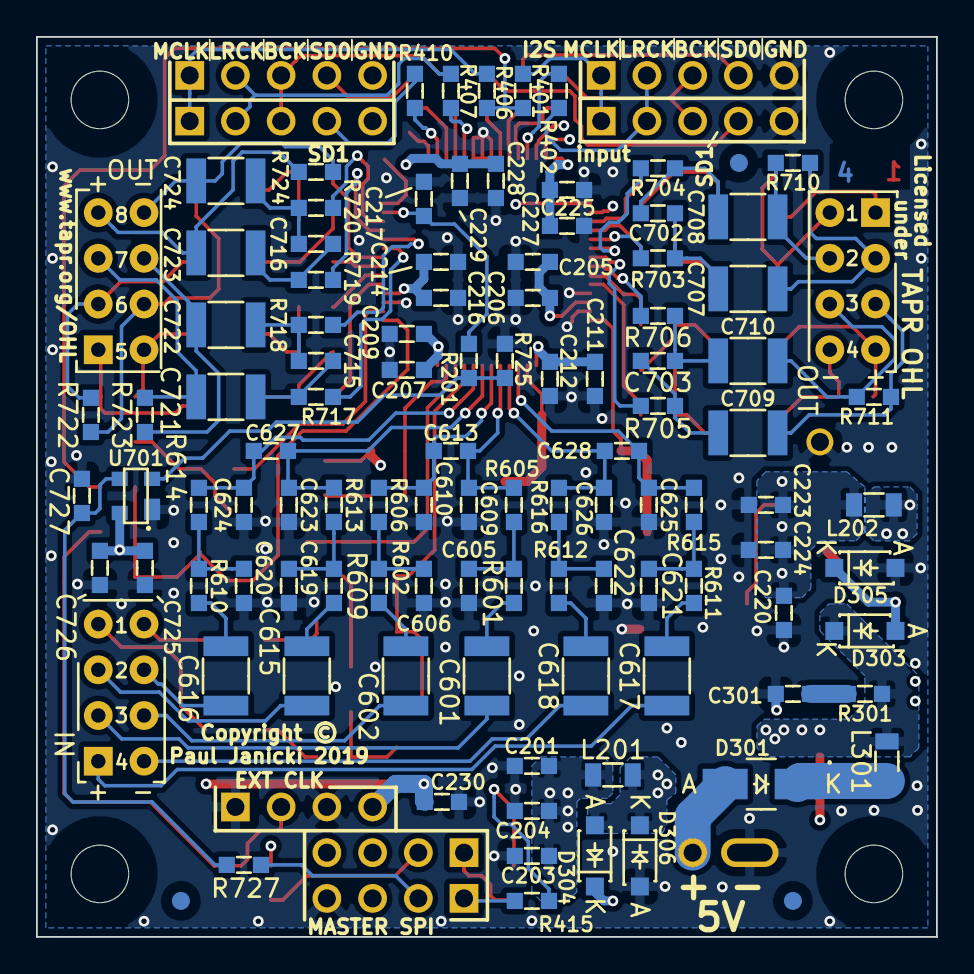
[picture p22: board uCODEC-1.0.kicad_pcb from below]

Board: 4 copper layers, 50.0 x 50.0 mm, 194 parts (104 on the bottom side), 130 nets.

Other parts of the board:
C610: 1n; SMD-0603
C613: 100p; SMD-0603
R605, R606: 220; SMD-0603

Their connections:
/ADC1RN: C610.2, C613.2, R606.1; also elsewhere on the board

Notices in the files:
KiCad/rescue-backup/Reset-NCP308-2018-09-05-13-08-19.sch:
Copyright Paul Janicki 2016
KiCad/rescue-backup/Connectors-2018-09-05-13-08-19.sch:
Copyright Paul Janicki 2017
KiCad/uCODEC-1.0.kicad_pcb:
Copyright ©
